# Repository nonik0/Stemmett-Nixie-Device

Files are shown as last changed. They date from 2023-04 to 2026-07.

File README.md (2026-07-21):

# Stemmett Nixie Device

## Description
A Nixie device that uses front-viewed [PL31 socket](https://tubes-store.com/product_info.php?products_id=101) Nixie tubes ([IN-4](https://www.tube-tester.com/sites/nixie/data/in-4/in-4-sh2.htm), [IN-7](https://www.tube-tester.com/sites/nixie/data/IN-7/in-7.htm), [IN-7A](https://www.swissnixie.com/tubes/IN7A/), IN-7B) in different orientations to create makeshift letters and spell things like names! The main board itself has 6 sockets for custom PL31 breakout boards, which have the nixie tube sockets in different orientations to rotate the Nixie tubes. By rotating the tubes we can pseudo-spell things, see images below for example (i.e. "7" rotated 180° to be an "L", or "m" rotated -90° to be a small-sized "E").

The hardware is designed in KiCad and all design files are included in the hardware directory. The hardware consists of the design of the main board PCB and three different versions of the PL31 socket breakout boards. The overall component choices target using simple through-hole components so the PCB is easier to debug, as it is my first PCB design. All cathodes of the nixie tubes are controlled with a single pin with serial, using three 74HC595 shift registers to control the input of the six old school К155ИД1 (K155ID1, SN74141) driver chips for each nixie tube. Each tube anode has a simple MOSFET circuit to be able to PWM each tube individually, allowing each tube to be individually dimmed or turned off. I am using the tiny awesome [NCH8200HV](https://www.tindie.com/products/omnixie/nch8200hv-nixie-high-voltage-power-module/) for the high voltage supply.

The firmware is a PlatformIO-based project targetting the [TinyS3](https://esp32s3.com/tinys3.html) ESP32 dev board. All source files are included in the firmware directory. The firmware will cycle through various different animations, returning to the configured name/word between each. It has a basic HTTP UX with REST interface to update settings--enable/disable animations, changing brightness, etc. It is simple to customize the firmware to any tube configuration by creating a new one in [tubeConfiguration.h](firmware/tubeConfiguration.h).

## Bowen Nixie Device
See the [Bowen Nixie Device README](hardware/kicad/bowen-nixie-device/README.md).

## Images

#### PCB Layout and Bare PCBs
circuitboard
photoof2devices

#### Wood Block to Enclosure
<p align="center" width="100%">
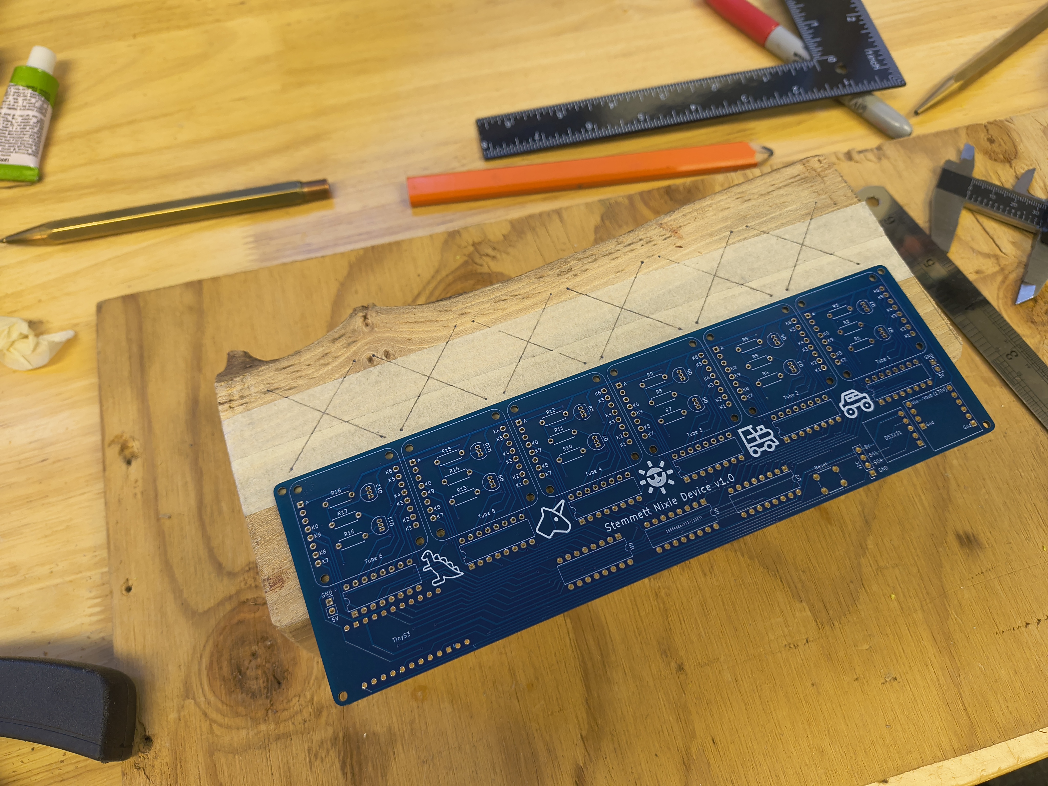
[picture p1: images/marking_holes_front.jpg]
  
</p>
<p align="center" width="100%">
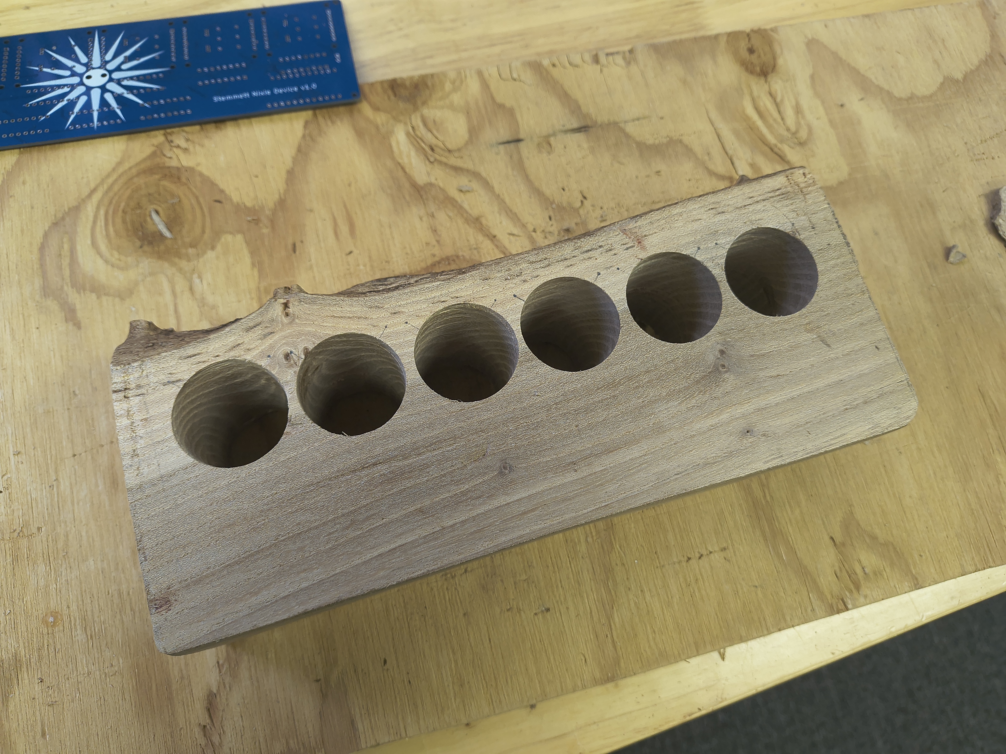
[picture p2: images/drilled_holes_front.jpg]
  
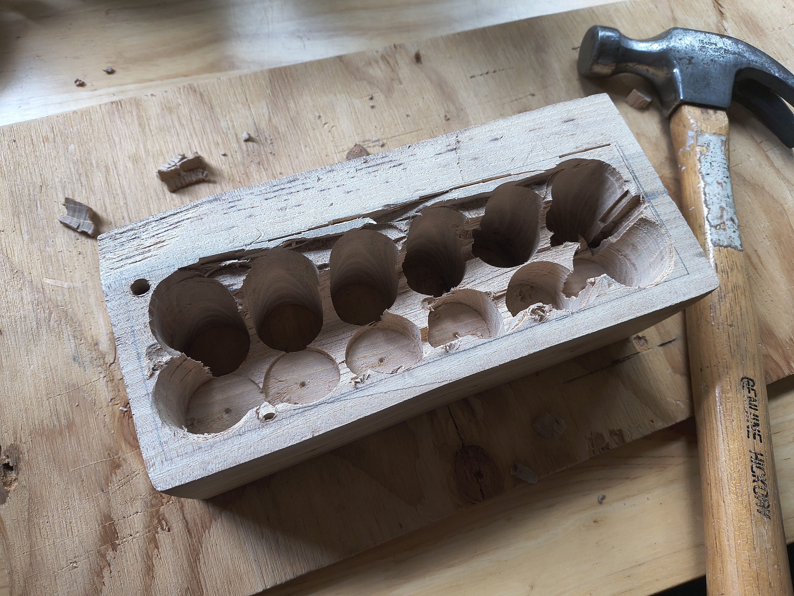
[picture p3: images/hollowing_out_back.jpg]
  
</p>
<p align="center" width="100%">
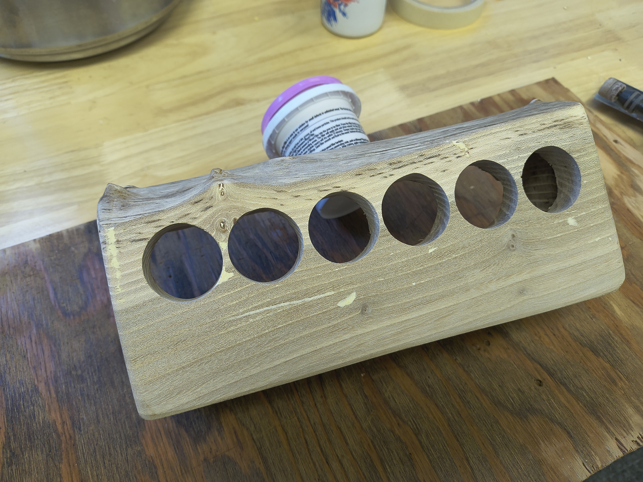
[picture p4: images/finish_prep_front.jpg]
  
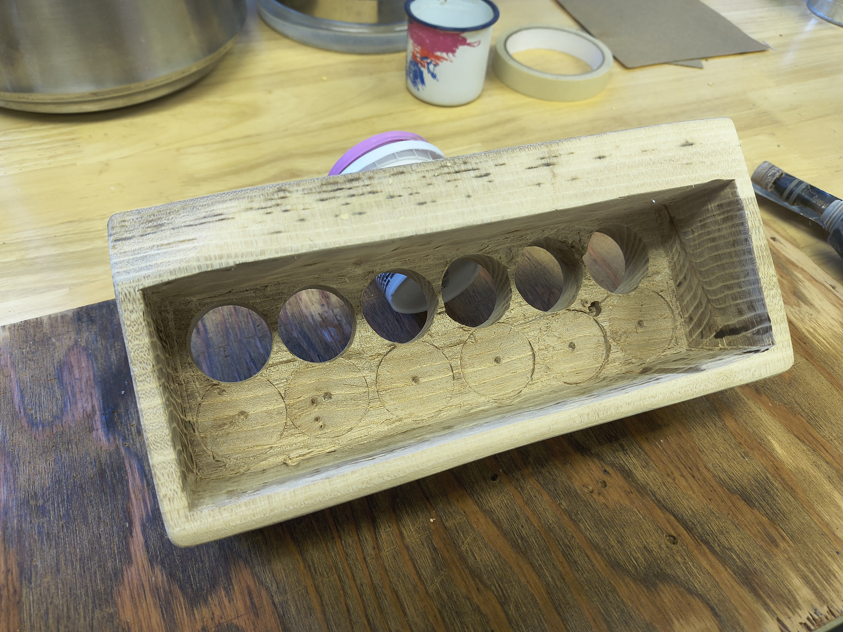
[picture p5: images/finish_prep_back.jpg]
  
</p>

#### Fitting and Finishing

<p align="center" width="100%">
  
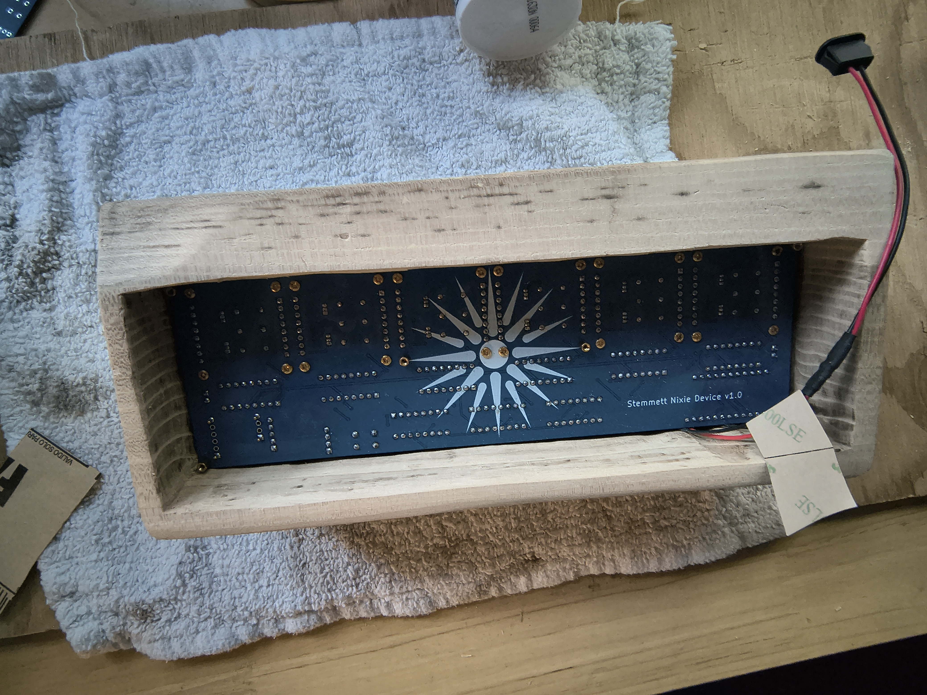
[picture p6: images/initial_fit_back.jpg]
  
</p>
<p align="center" width="100%">
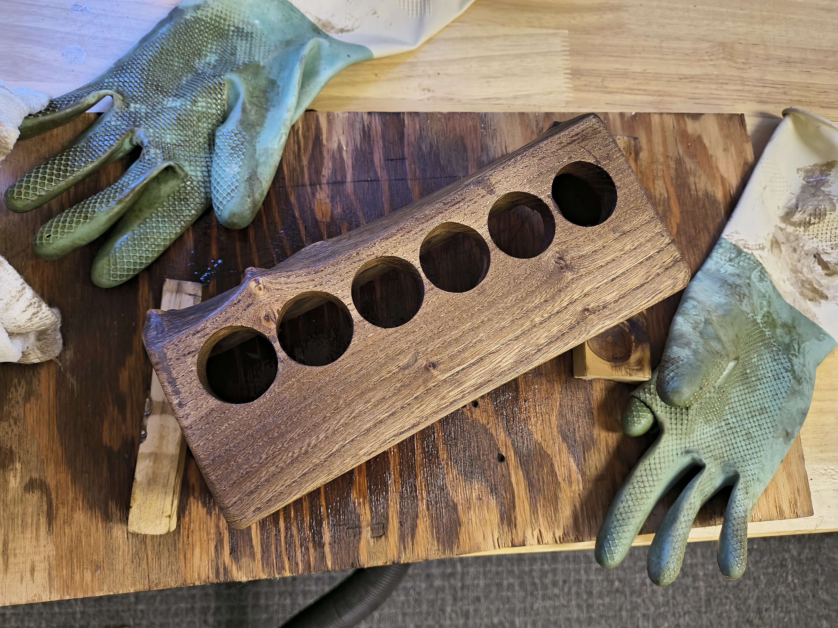
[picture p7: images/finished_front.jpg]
  
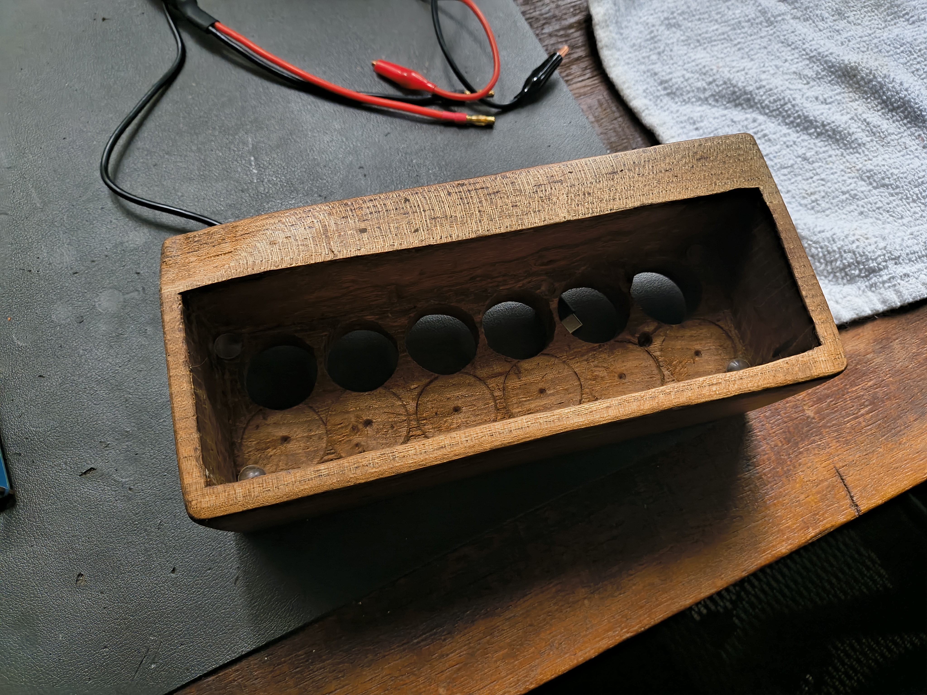
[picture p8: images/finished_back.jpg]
  
</p>

#### Finished Enclosure

<p align="center" width="100%">
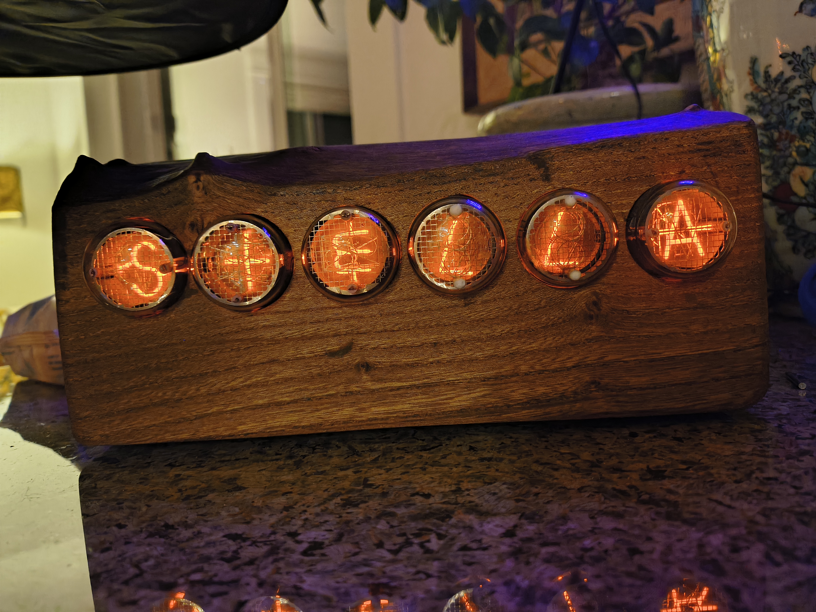
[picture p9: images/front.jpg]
  
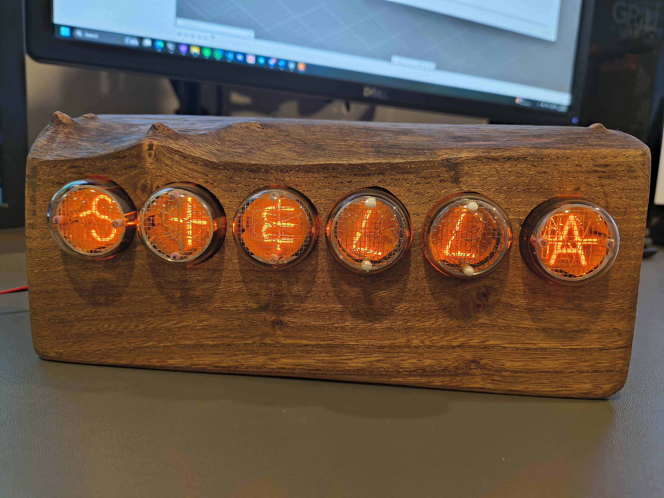
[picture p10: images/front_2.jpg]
  
</p>

#### Alternate Enclosure
<p align="center" width="100%">
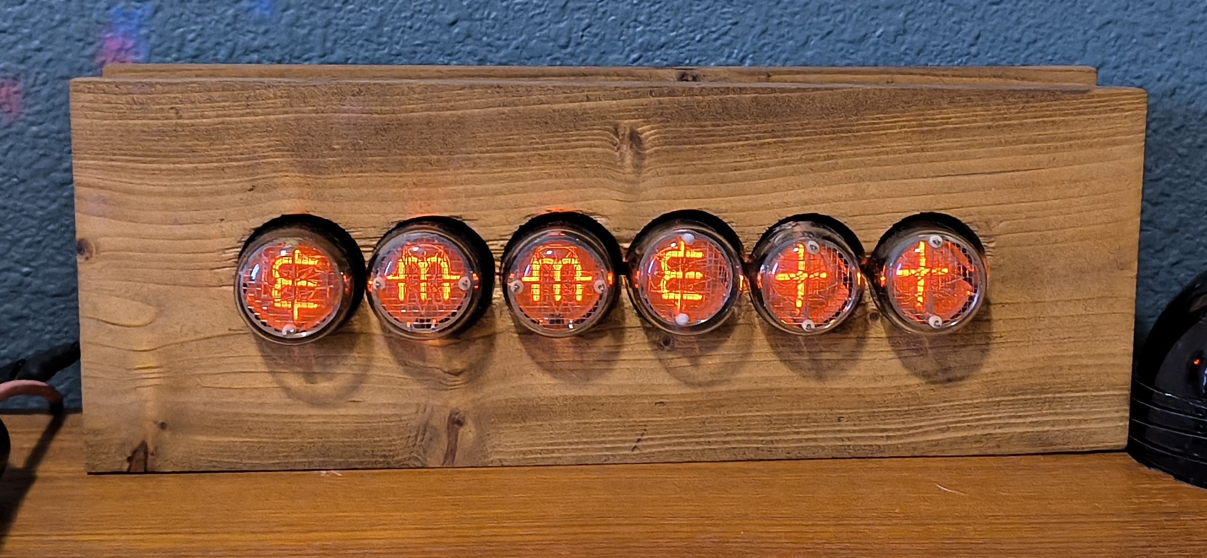
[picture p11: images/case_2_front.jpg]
  
</p>

## Animations

<a href="images/glitch_anim.mp4">Glitch Animation</a>
<a href="images/random_scan_anim.mp4">Random Scan Animation</a>







TODO: animations in better lighting...

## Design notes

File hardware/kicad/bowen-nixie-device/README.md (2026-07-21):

# Bowen Nixie Device

## Description
A Nixie device that is a successor/companion to the original Stemmett Nixie Device. Like its predecessor, it uses front-viewed [PL31 socket](https://tubes-store.com/product_info.php?products_id=101) Nixie tubes ([IN-4](https://www.tube-tester.com/sites/nixie/data/in-4/in-4-sh2.htm), [IN-7](https://www.tube-tester.com/sites/nixie/data/IN-7/in-7.htm), [IN-7A](https://www.swissnixie.com/tubes/IN7A/), IN-7B) to spell words with makeshift letters. These Nixie tubes plug into custom PL31 breakout boards which orient the tubes in different rotations. Then these tube breakout boards plug into the main board that supports control of 4 tubes in total. More breakout board variations were added from the original project to enable more letter possible.

Bowen Nixie Device differs from the prior project primarily through some different component choices. In this version, I am primarily using SMD components and have included discrete cathode control for each tube, i.e. every cathode gets its own transistor for control. Cathode control remains the same as before, using a series of shift registers to control the gate for each transistor that controls the cathode on each tube. Each tube still has an anode control circuit for switching the high voltage on the tube's anode, allowing manual control of each tube's brightness with PWM. 

Hardware prototype is pending, firmware

## Work Left
- get new main board and tube breakout boards made
- create initial prototype, vet hardware design
- update existing firmware to work with new board and tube configuration

## Images

#### PCB Layout
schematic
<img width="1062" alt="layout" src="https://github.com/user-attachments/assets/d3f8a463-915f-4086-bd1c-70b7b26c18d1"">

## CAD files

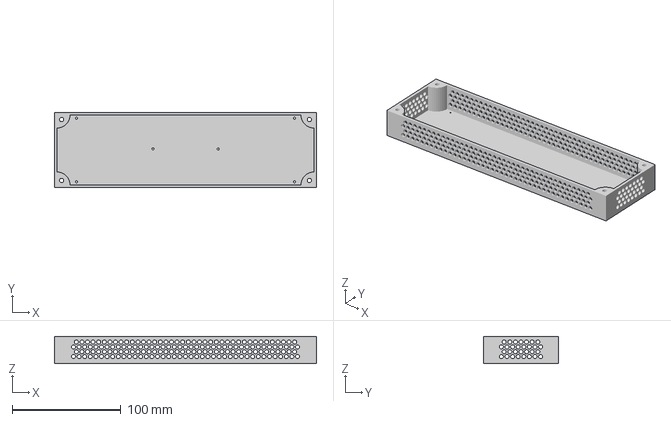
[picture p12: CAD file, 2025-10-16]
hardware/Stemmett Shroud.3mf
240.5 x 68.9 x 25.0 mm

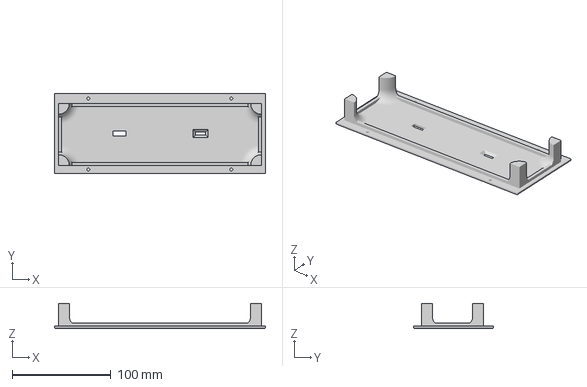
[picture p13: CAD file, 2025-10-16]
hardware/Stemmett Case Backplate.3mf
214.0 x 81.0 x 25.5 mm

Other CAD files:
hardware/Stemmett Case Backplate.f3d
hardware/Stemmett Shroud.f3d

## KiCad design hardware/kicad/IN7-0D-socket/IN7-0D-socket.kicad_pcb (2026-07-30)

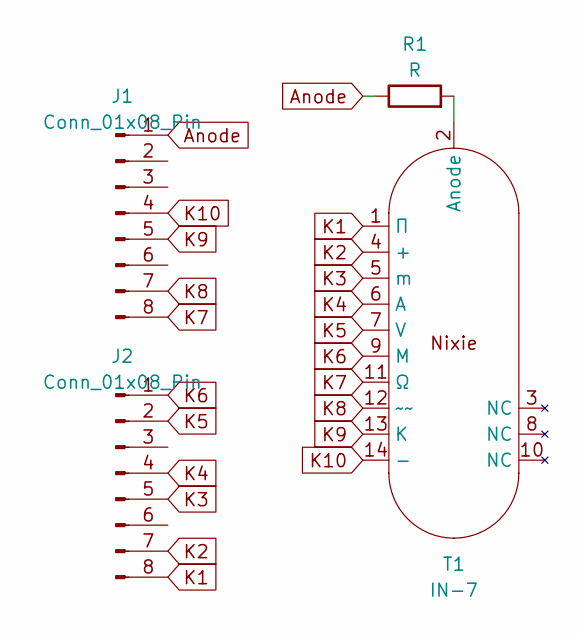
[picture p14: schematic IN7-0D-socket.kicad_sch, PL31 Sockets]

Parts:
J1, J2: Conn_01x08_Pin; PinHeader_1x08_P2.54mm_Vertical
R1: R; R_Axial_DIN0207_L6.3mm_D2.5mm_P7.62mm_Horizontal
T1: IN-7; PL31 (IN4 family)

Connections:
Anode: J1.1, R1.1
K1: J2.8, T1.1 (П)
K2: J2.7, T1.4 (+)
K3: J2.5, T1.5 (m)
K4: J2.4, T1.6 (A)
K5: J2.2, T1.7 (V)
K6: J2.1, T1.9 (M)
K7: J1.8, T1.11 (Ω)
K8: J1.7, T1.12 (~~)
K9: J1.5, T1.13 (К)
K10: J1.4, T1.14 (-)
unnamed: R1.2, T1.2 (Anode)

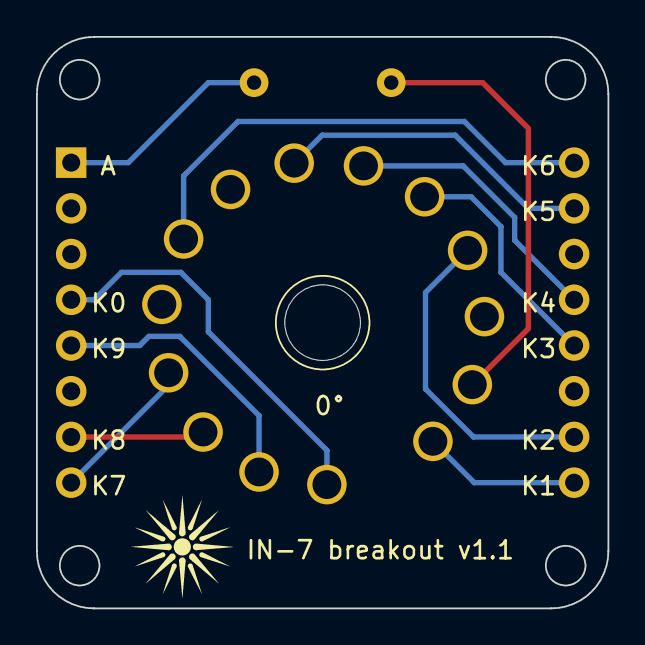
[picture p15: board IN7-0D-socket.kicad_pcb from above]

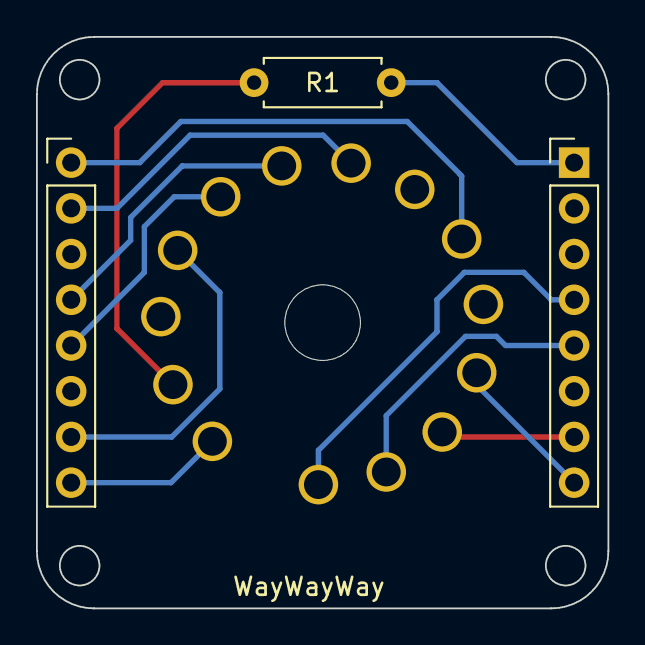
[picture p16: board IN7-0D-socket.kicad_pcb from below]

Board: 2 copper layers, 31.8 x 31.8 mm, 4 parts (3 on the bottom side), 12 nets.

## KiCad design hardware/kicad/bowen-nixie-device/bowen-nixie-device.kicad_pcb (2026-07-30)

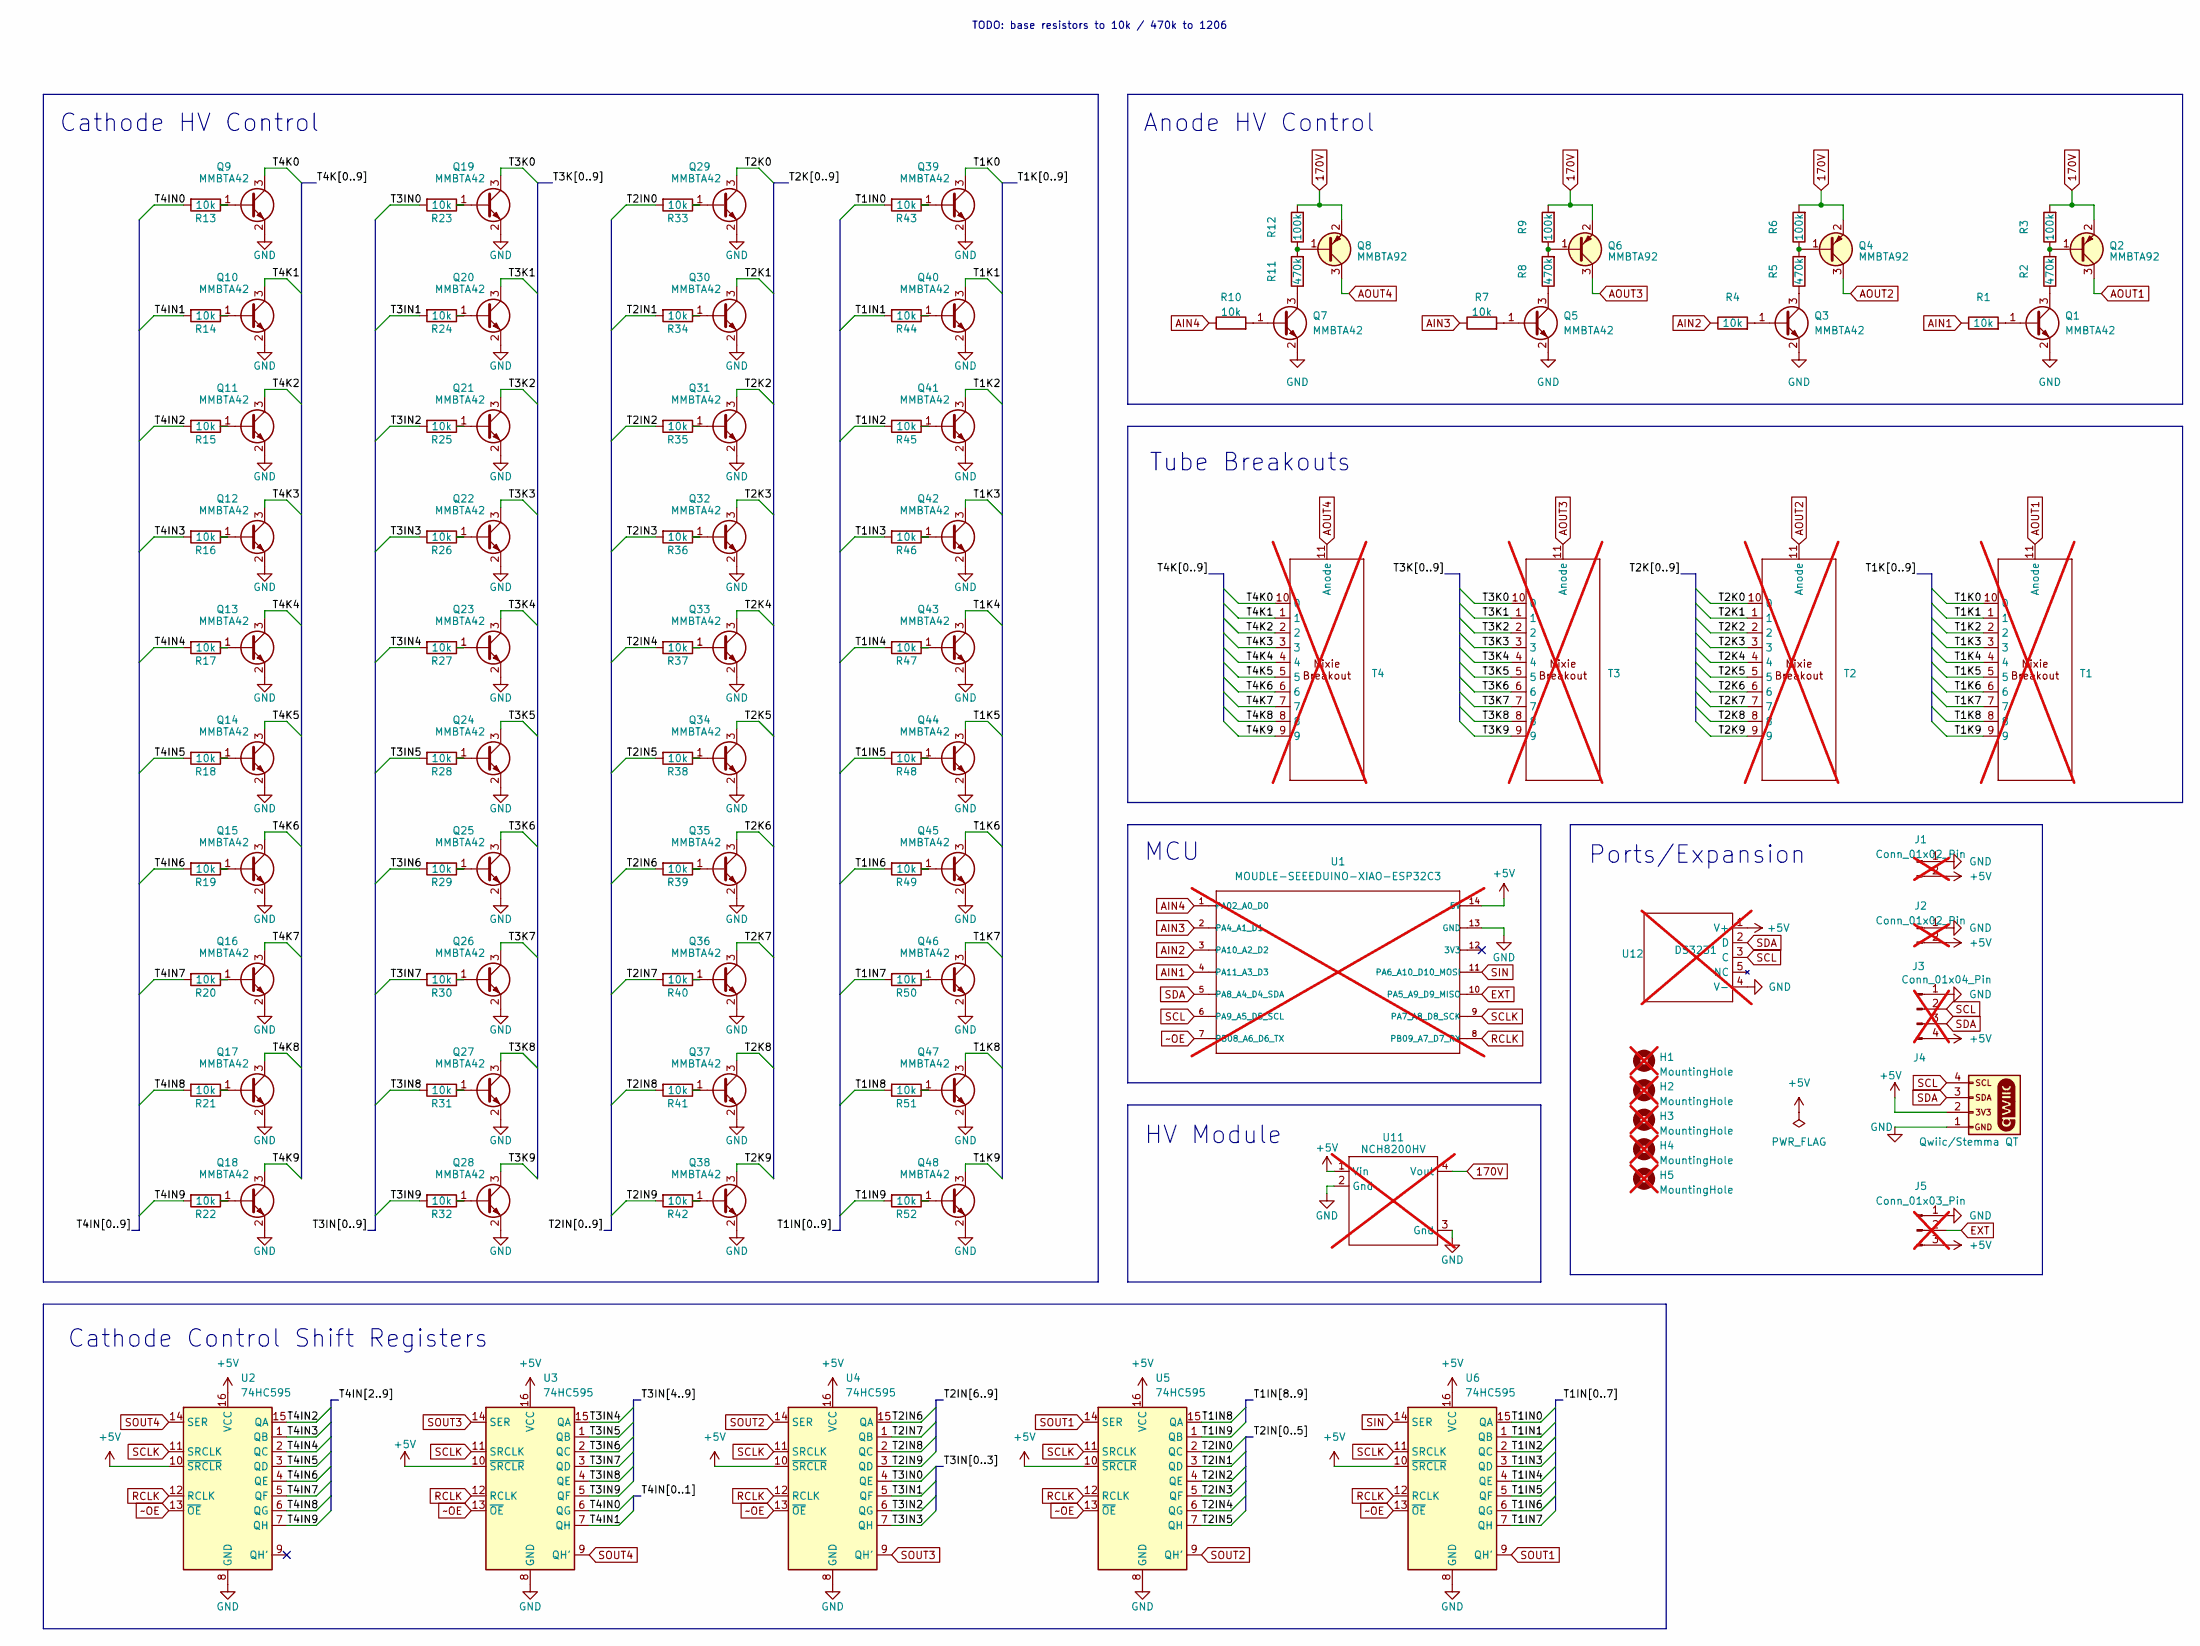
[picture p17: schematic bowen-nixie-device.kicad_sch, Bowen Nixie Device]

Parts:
H1, H2, H3, H4, H5: MountingHole; MountingHole_2.2mm_M2_DIN965_Pad; not fitted
J1, J2: Conn_01x02_Pin; PinSocket_1x02_P2.54mm_Vertical; not fitted
J3: Conn_01x04_Pin; PinSocket_1x04_P2.54mm_Vertical; not fitted
J4: Qwiic/Stemma QT; JST_1x04_P1.0mm_Vertical_SMD
J5: Conn_01x03_Pin; PinSocket_1x03_P2.54mm_Vertical; not fitted
Q1, Q3, Q5, Q7, Q9, Q10, Q11, Q12, Q13, Q14, Q15, Q16, Q17, Q18, Q19, Q20, Q21, Q22, Q23, Q24, Q25, Q26, Q27, Q28, Q29, Q30, Q31, Q32, Q33, Q34, Q35, Q36, Q37, Q38, Q39, Q40, Q41, Q42, Q43, Q44, Q45, Q46, Q47, Q48: MMBTA42; SOT-23
Q2, Q4, Q6, Q8: MMBTA92; SOT-23
R1, R4, R7, R10, R13, R14, R15, R16, R17, R18, R19, R20, R21, R22, R23, R24, R25, R26, R27, R28, R29, R30, R31, R32, R33, R34, R35, R36, R37, R38, R39, R40, R41, R42, R43, R44, R45, R46, R47, R48, R49, R50, R51, R52: 10k; R_0603_1608Metric
R2, R5, R8, R11: 470k; R_1206_3216Metric
R3, R6, R9, R12: 100k; R_0603_1608Metric
T1, T2, T3, T4: PL31 Socket Breakout; not fitted
U1: MOUDLE-SEEEDUINO-XIAO-ESP32C3; XIAO-ESP32-C3-DIP; not fitted
U2, U3, U4, U5, U6: 74HC595; SOIC-16_4.55x10.3mm_P1.27mm
U11: NCH8200HV; not fitted
U12: DS3231; DS3231 Breakout; not fitted

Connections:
170V: Q2.2 (E), Q4.2 (E), Q6.2 (E), Q8.2 (E), R3.2, R6.2, R9.2, R12.2, U11.4 (Vout)
+5V: J1.2, J2.2, J3.4, J4.2, J5.3, U1.14 (5V), U2.10 (~SRCLR), U2.16 (VCC), U3.10 (~SRCLR), U3.16 (VCC), U4.10 (~SRCLR), U4.16 (VCC), U5.10 (~SRCLR), U5.16 (VCC), U6.10 (~SRCLR), U6.16 (VCC), U11.1 (Vin), U12.1 (V+)
/T1IN0: R43.2, U6.15 (QA)
/T1IN1: R44.2, U6.1 (QB)
/T1IN2: R45.2, U6.2 (QC)
/T1IN3: R46.2, U6.3 (QD)
/T1IN4: R47.2, U6.4 (QE)
/T1IN5: R48.2, U6.5 (QF)
/T1IN6: R49.2, U6.6 (QG)
/T1IN7: R50.2, U6.7 (QH)
/T1IN8: R51.2, U5.15 (QA)
/T1IN9: R52.2, U5.1 (QB)
/T1K0: Q39.3 (C), T1.10 (0)
/T1K1: Q40.3 (C), T1.1
/T1K2: Q41.3 (C), T1.2
/T1K3: Q42.3 (C), T1.3
/T1K4: Q43.3 (C), T1.4
/T1K5: Q44.3 (C), T1.5
/T1K6: Q45.3 (C), T1.6
/T1K7: Q46.3 (C), T1.7
/T1K8: Q47.3 (C), T1.8
/T1K9: Q48.3 (C), T1.9
/T2IN0: R33.2, U5.2 (QC)
/T2IN1: R34.2, U5.3 (QD)
/T2IN2: R35.2, U5.4 (QE)
/T2IN3: R36.2, U5.5 (QF)
/T2IN4: R37.2, U5.6 (QG)
/T2IN5: R38.2, U5.7 (QH)
/T2IN6: R39.2, U4.15 (QA)
/T2IN7: R40.2, U4.1 (QB)
/T2IN8: R41.2, U4.2 (QC)
/T2IN9: R42.2, U4.3 (QD)
/T2K0: Q29.3 (C), T2.10 (0)
/T2K1: Q30.3 (C), T2.1
/T2K2: Q31.3 (C), T2.2
/T2K3: Q32.3 (C), T2.3
/T2K4: Q33.3 (C), T2.4
/T2K5: Q34.3 (C), T2.5
/T2K6: Q35.3 (C), T2.6
/T2K7: Q36.3 (C), T2.7
/T2K8: Q37.3 (C), T2.8
/T2K9: Q38.3 (C), T2.9
/T3IN0: R23.2, U4.4 (QE)
/T3IN1: R24.2, U4.5 (QF)
/T3IN2: R25.2, U4.6 (QG)
/T3IN3: R26.2, U4.7 (QH)
/T3IN4: R27.2, U3.15 (QA)
/T3IN5: R28.2, U3.1 (QB)
/T3IN6: R29.2, U3.2 (QC)
/T3IN7: R30.2, U3.3 (QD)
/T3IN8: R31.2, U3.4 (QE)
/T3IN9: R32.2, U3.5 (QF)
/T3K0: Q19.3 (C), T3.10 (0)
/T3K1: Q20.3 (C), T3.1
/T3K2: Q21.3 (C), T3.2
/T3K3: Q22.3 (C), T3.3
/T3K4: Q23.3 (C), T3.4
/T3K5: Q24.3 (C), T3.5
/T3K6: Q25.3 (C), T3.6
/T3K7: Q26.3 (C), T3.7
/T3K8: Q27.3 (C), T3.8
/T3K9: Q28.3 (C), T3.9
/T4IN0: R13.2, U3.6 (QG)
/T4IN1: R14.2, U3.7 (QH)
/T4IN2: R15.2, U2.15 (QA)
/T4IN3: R16.2, U2.1 (QB)
/T4IN4: R17.2, U2.2 (QC)
/T4IN5: R18.2, U2.3 (QD)
/T4IN6: R19.2, U2.4 (QE)
/T4IN7: R20.2, U2.5 (QF)
/T4IN8: R21.2, U2.6 (QG)
/T4IN9: R22.2, U2.7 (QH)
/T4K0: Q9.3 (C), T4.10 (0)
/T4K1: Q10.3 (C), T4.1
/T4K2: Q11.3 (C), T4.2
/T4K3: Q12.3 (C), T4.3
/T4K4: Q13.3 (C), T4.4
/T4K5: Q14.3 (C), T4.5
/T4K6: Q15.3 (C), T4.6
/T4K7: Q16.3 (C), T4.7
/T4K8: Q17.3 (C), T4.8
/T4K9: Q18.3 (C), T4.9
AIN1: R1.1, U1.4 (PA11_A3_D3)
AIN2: R4.1, U1.3 (PA10_A2_D2)
AIN3: R7.1, U1.2 (PA4_A1_D1)
AIN4: R10.1, U1.1 (PA02_A0_D0)
AOUT1: Q2.3 (C), T1.11 (Anode)
AOUT2: Q4.3 (C), T2.11 (Anode)
AOUT3: Q6.3 (C), T3.11 (Anode)
AOUT4: Q8.3 (C), T4.11 (Anode)
EXT: J5.2, U1.10 (PA5_A9_D9_MISO)
GND: J1.1, J2.1, J3.1, J4.1, J5.1, Q1.2 (E), Q3.2 (E), Q5.2 (E), Q7.2 (E), Q9.2 (E), Q10.2 (E), Q11.2 (E), Q12.2 (E), Q13.2 (E), Q14.2 (E), Q15.2 (E), Q16.2 (E), Q17.2 (E), Q18.2 (E), Q19.2 (E), Q20.2 (E), Q21.2 (E), Q22.2 (E), Q23.2 (E), Q24.2 (E), Q25.2 (E), Q26.2 (E), Q27.2 (E), Q28.2 (E), Q29.2 (E), Q30.2 (E), Q31.2 (E), Q32.2 (E), Q33.2 (E), Q34.2 (E), Q35.2 (E), Q36.2 (E), Q37.2 (E), Q38.2 (E), Q39.2 (E), Q40.2 (E), Q41.2 (E), Q42.2 (E), Q43.2 (E), Q44.2 (E), Q45.2 (E), Q46.2 (E), Q47.2 (E), Q48.2 (E), U1.13 (GND), U2.8 (GND), U3.8 (GND), U4.8 (GND), U5.8 (GND), U6.8 (GND), U11.2 (Gnd), U11.3 (Gnd), U12.4 (V-)
unnamed: Q1.1 (B), R1.2
unnamed: Q1.3 (C), R2.1
unnamed: Q2.1 (B), R2.2, R3.1
unnamed: Q3.1 (B), R4.2
unnamed: Q3.3 (C), R5.1
unnamed: Q4.1 (B), R5.2, R6.1
unnamed: Q5.1 (B), R7.2
unnamed: Q5.3 (C), R8.1
unnamed: Q6.1 (B), R8.2, R9.1
unnamed: Q7.1 (B), R10.2
unnamed: Q7.3 (C), R11.1
unnamed: Q8.1 (B), R11.2, R12.1
unnamed: Q9.1 (B), R13.1
unnamed: Q10.1 (B), R14.1
unnamed: Q11.1 (B), R15.1
unnamed: Q12.1 (B), R16.1
unnamed: Q13.1 (B), R17.1
unnamed: Q14.1 (B), R18.1
unnamed: Q15.1 (B), R19.1
unnamed: Q16.1 (B), R20.1
unnamed: Q17.1 (B), R21.1
unnamed: Q18.1 (B), R22.1
unnamed: Q19.1 (B), R23.1
unnamed: Q20.1 (B), R24.1
unnamed: Q21.1 (B), R25.1
unnamed: Q22.1 (B), R26.1
unnamed: Q23.1 (B), R27.1
unnamed: Q24.1 (B), R28.1
unnamed: Q25.1 (B), R29.1
unnamed: Q26.1 (B), R30.1
unnamed: Q27.1 (B), R31.1
unnamed: Q28.1 (B), R32.1
unnamed: Q29.1 (B), R33.1
unnamed: Q30.1 (B), R34.1
unnamed: Q31.1 (B), R35.1
unnamed: Q32.1 (B), R36.1
unnamed: Q33.1 (B), R37.1
unnamed: Q34.1 (B), R38.1
unnamed: Q35.1 (B), R39.1
unnamed: Q36.1 (B), R40.1
unnamed: Q37.1 (B), R41.1
unnamed: Q38.1 (B), R42.1
unnamed: Q39.1 (B), R43.1
unnamed: Q40.1 (B), R44.1
unnamed: Q41.1 (B), R45.1
unnamed: Q42.1 (B), R46.1
unnamed: Q43.1 (B), R47.1
unnamed: Q44.1 (B), R48.1
unnamed: Q45.1 (B), R49.1
unnamed: Q46.1 (B), R50.1
unnamed: Q47.1 (B), R51.1
unnamed: Q48.1 (B), R52.1
RCLK: U1.8 (PB09_A7_D7_RX), U2.12 (RCLK), U3.12 (RCLK), U4.12 (RCLK), U5.12 (RCLK), U6.12 (RCLK)
SCL: J3.2, J4.4, U1.6 (PA9_A5_D5_SCL), U12.3 (C)
SCLK: U1.9 (PA7_A8_D8_SCK), U2.11 (SRCLK), U3.11 (SRCLK), U4.11 (SRCLK), U5.11 (SRCLK), U6.11 (SRCLK)
SDA: J3.3, J4.3, U1.5 (PA8_A4_D4_SDA), U12.2 (D)
SIN: U1.11 (PA6_A10_D10_MOSI), U6.14 (SER)
SOUT1: U5.14 (SER), U6.9 (QH')
SOUT2: U4.14 (SER), U5.9 (QH')
SOUT3: U3.14 (SER), U4.9 (QH')
SOUT4: U2.14 (SER), U3.9 (QH')
~OE: U1.7 (PB08_A6_D6_TX), U2.13 (~OE), U3.13 (~OE), U4.13 (~OE), U5.13 (~OE), U6.13 (~OE)

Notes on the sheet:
TODO: base resistors to 10k / 470k to 1206
Cathode Control Shift Registers
Cathode HV Control
HV Module
Anode HV Control
Tube Breakouts
Ports/Expansion
MCU

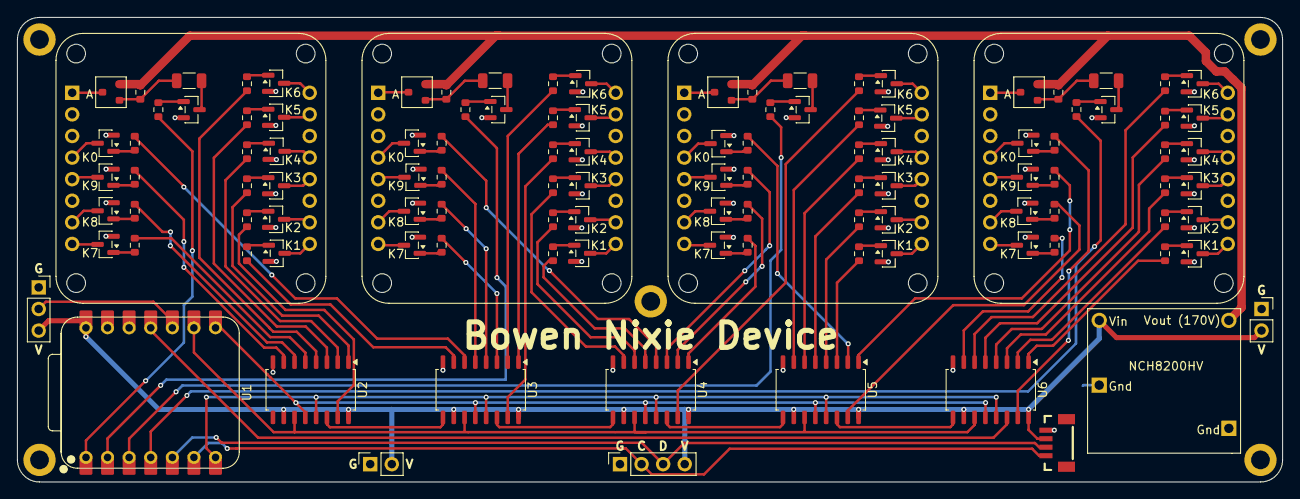
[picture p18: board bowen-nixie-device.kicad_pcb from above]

Board: 2 copper layers, 148.8 x 54.6 mm, 121 parts (0 on the bottom side), 154 nets.

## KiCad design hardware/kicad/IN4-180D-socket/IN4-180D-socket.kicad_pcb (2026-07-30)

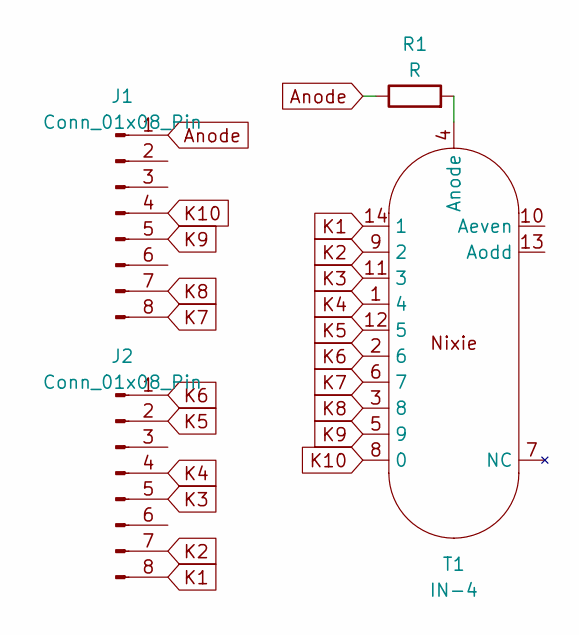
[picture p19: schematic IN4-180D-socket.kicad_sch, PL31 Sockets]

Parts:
J1, J2: Conn_01x08_Pin; PinHeader_1x08_P2.54mm_Vertical
R1: R; R_Axial_DIN0207_L6.3mm_D2.5mm_P7.62mm_Horizontal
T1: IN-4; PL31 (IN4 rotation)

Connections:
Anode: J1.1, R1.1
K1: J2.8, T1.14 (1)
K2: J2.7, T1.9 (2)
K3: J2.5, T1.11 (3)
K4: J2.4, T1.1 (4)
K5: J2.2, T1.12 (5)
K6: J2.1, T1.2 (6)
K7: J1.8, T1.6 (7)
K8: J1.7, T1.3 (8)
K9: J1.5, T1.5 (9)
K10: J1.4, T1.8 (0)
unnamed: R1.2, T1.4 (Anode)

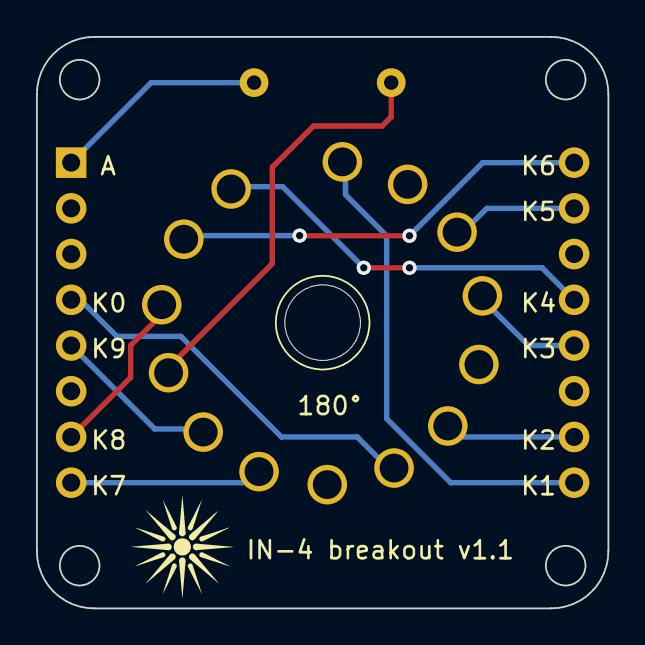
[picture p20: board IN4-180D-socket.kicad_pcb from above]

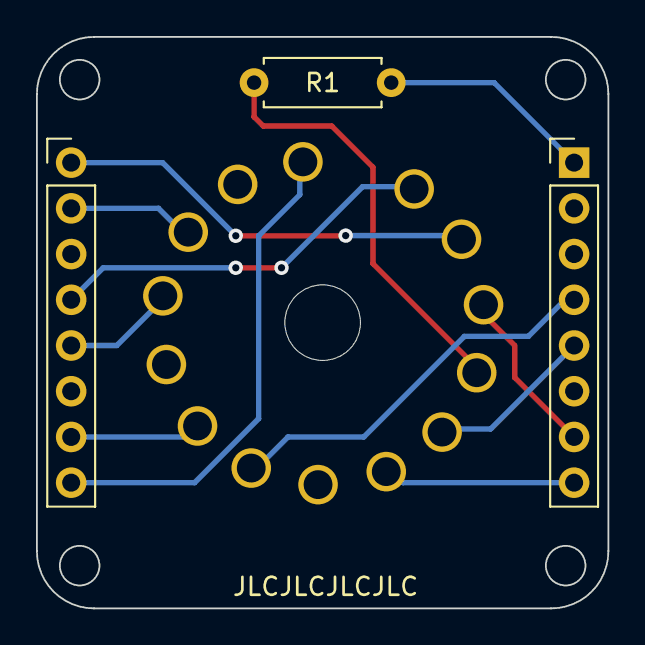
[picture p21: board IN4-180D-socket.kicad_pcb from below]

Board: 2 copper layers, 31.8 x 31.8 mm, 4 parts (3 on the bottom side), 12 nets.

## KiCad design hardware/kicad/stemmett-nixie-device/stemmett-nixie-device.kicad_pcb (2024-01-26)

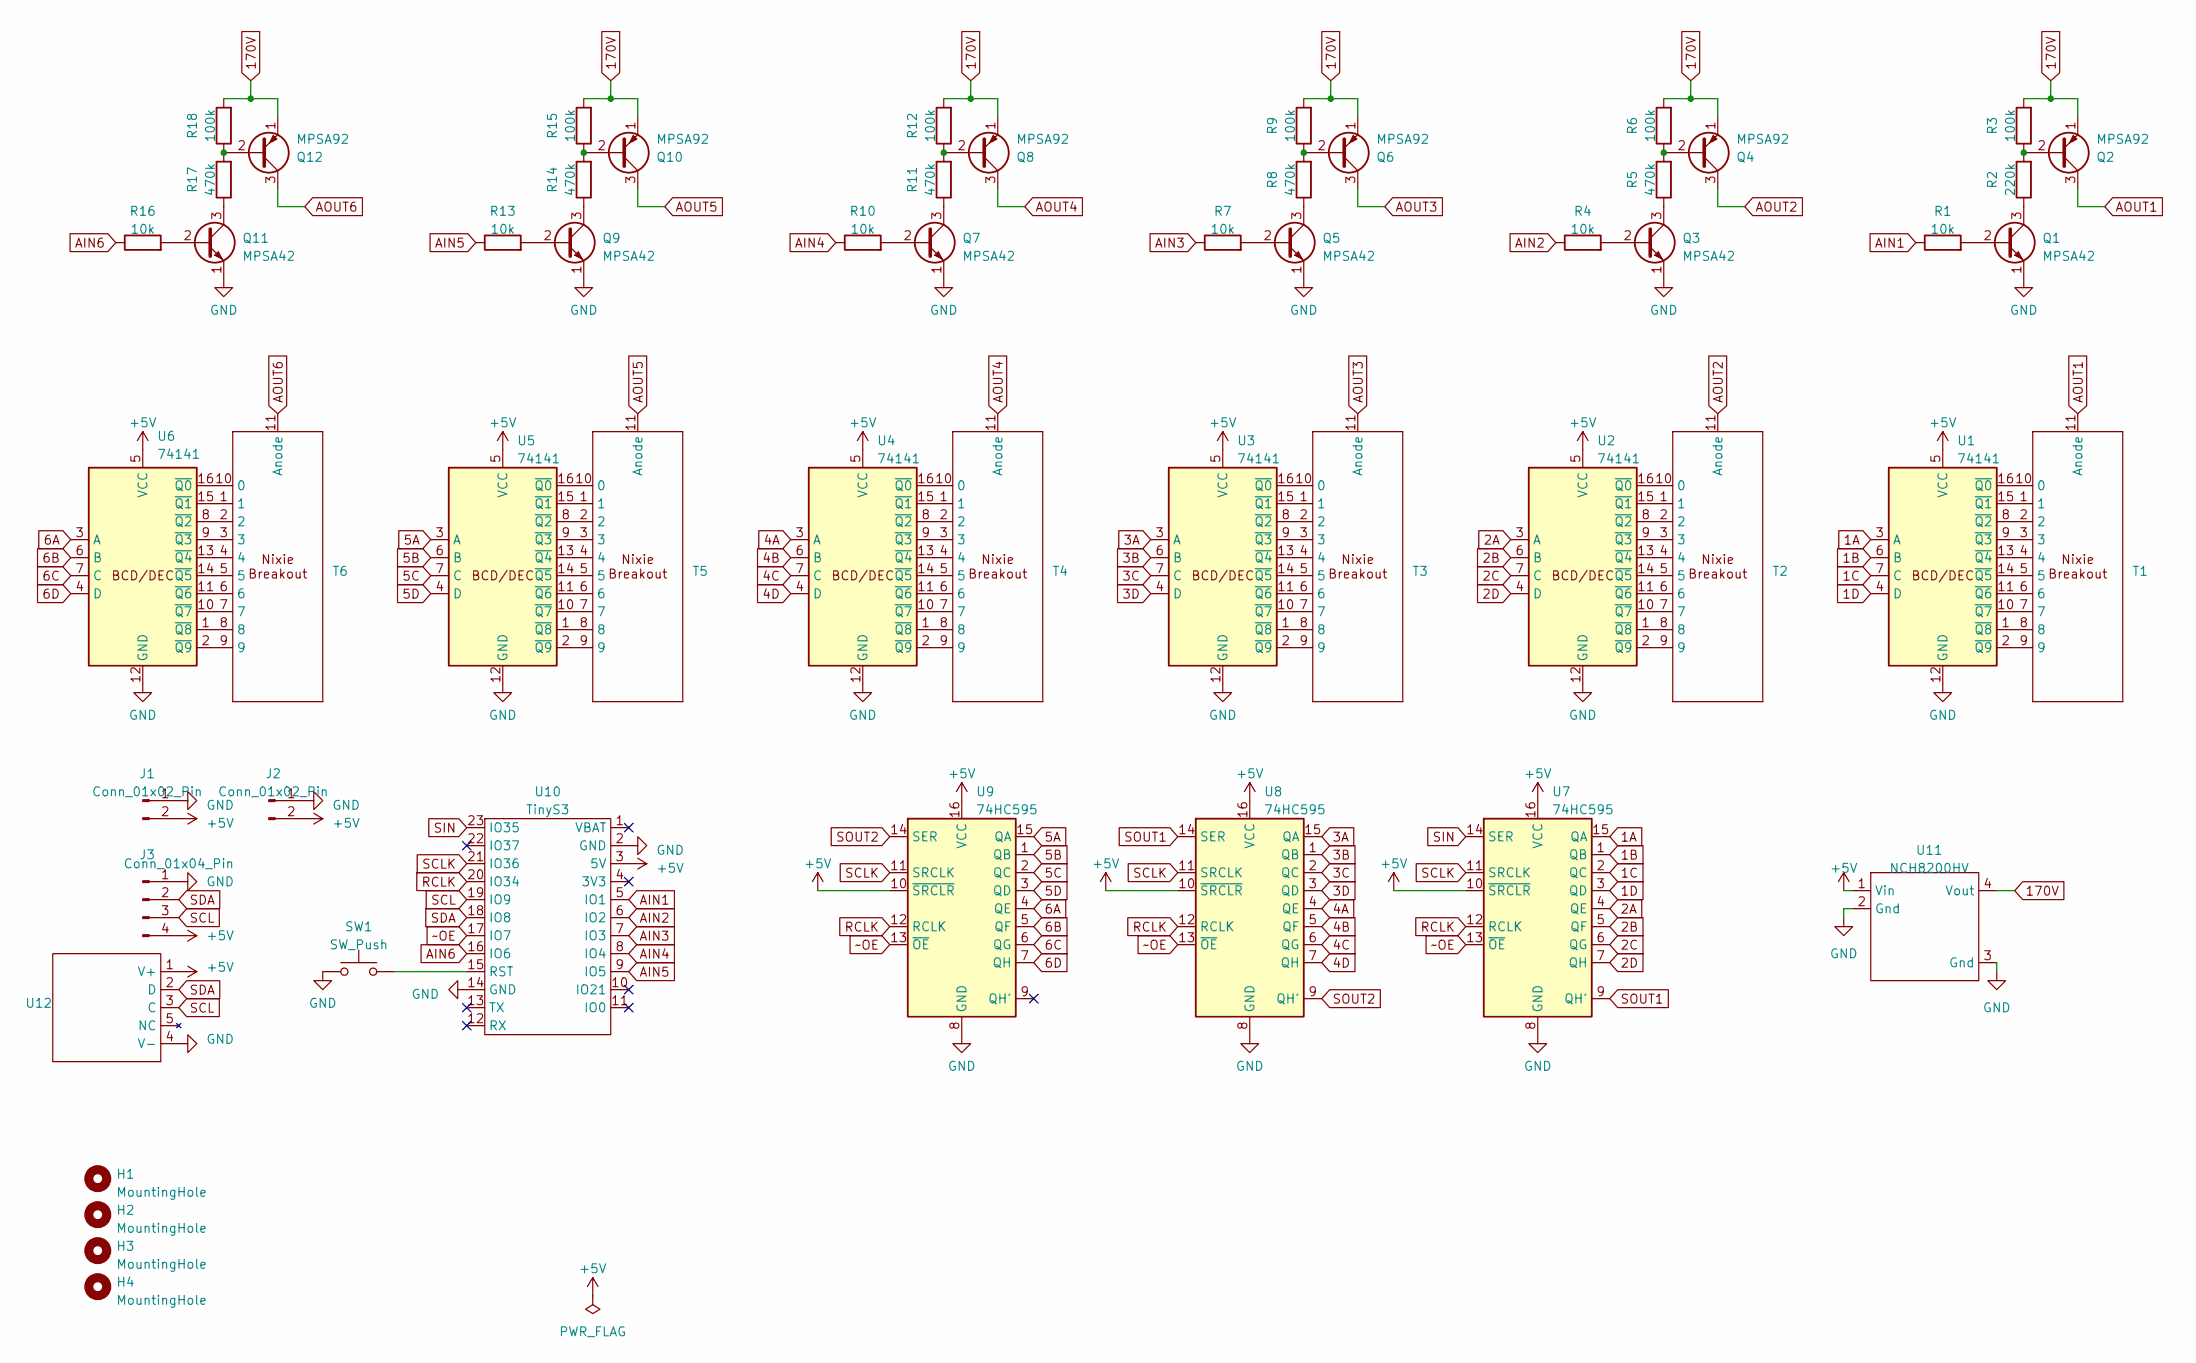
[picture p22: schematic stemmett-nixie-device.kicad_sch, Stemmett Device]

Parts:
H1, H2, H3, H4: MountingHole; MountingHole_2.2mm_M2
J1, J2: Conn_01x02_Pin; PinSocket_1x02_P2.54mm_Vertical
J3: Conn_01x04_Pin; PinSocket_1x04_P2.54mm_Vertical
Q1, Q3, Q5, Q7, Q9, Q11: MPSA42; TO-92_Inline
Q2, Q4, Q6, Q8, Q10, Q12: MPSA92; TO-92_Inline
R1, R4, R7, R10, R13, R16: 10k; R_Axial_DIN0207_L6.3mm_D2.5mm_P7.62mm_Horizontal
R2: 220k; R_Axial_DIN0207_L6.3mm_D2.5mm_P7.62mm_Horizontal
R3, R6, R9, R12, R15, R18: 100k; R_Axial_DIN0207_L6.3mm_D2.5mm_P7.62mm_Horizontal
R5, R8, R11, R14, R17: 470k; R_Axial_DIN0207_L6.3mm_D2.5mm_P7.62mm_Horizontal
SW1: SW_Push; SW_PUSH_6mm
T1, T2, T3, T4, T5, T6: PL31 Socket Breakout
U1, U2, U3, U4, U5, U6: 74141; DIP-16_W7.62mm
U7, U8, U9: 74HC595; DIP-16_W7.62mm
U10: TinyS3
U11: NCH8200HV
U12: DS3231 Breakout

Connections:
1A: U1.3 (A), U7.15 (QA)
1B: U1.6 (B), U7.1 (QB)
1C: U1.7 (C), U7.2 (QC)
1D: U1.4 (D), U7.3 (QD)
2A: U2.3 (A), U7.4 (QE)
2B: U2.6 (B), U7.5 (QF)
2C: U2.7 (C), U7.6 (QG)
2D: U2.4 (D), U7.7 (QH)
3A: U3.3 (A), U8.15 (QA)
3B: U3.6 (B), U8.1 (QB)
3C: U3.7 (C), U8.2 (QC)
3D: U3.4 (D), U8.3 (QD)
4A: U4.3 (A), U8.4 (QE)
4B: U4.6 (B), U8.5 (QF)
4C: U4.7 (C), U8.6 (QG)
4D: U4.4 (D), U8.7 (QH)
5A: U5.3 (A), U9.15 (QA)
5B: U5.6 (B), U9.1 (QB)
5C: U5.7 (C), U9.2 (QC)
5D: U5.4 (D), U9.3 (QD)
6A: U6.3 (A), U9.4 (QE)
6B: U6.6 (B), U9.5 (QF)
6C: U6.7 (C), U9.6 (QG)
6D: U6.4 (D), U9.7 (QH)
170V: Q2.1 (E), Q4.1 (E), Q6.1 (E), Q8.1 (E), Q10.1 (E), Q12.1 (E), R3.2, R6.2, R9.2, R12.2, R15.2, R18.2, U11.4 (Vout)
+5V: J1.2, J2.2, J3.4, U1.5 (VCC), U2.5 (VCC), U3.5 (VCC), U4.5 (VCC), U5.5 (VCC), U6.5 (VCC), U7.10 (~SRCLR), U7.16 (VCC), U8.10 (~SRCLR), U8.16 (VCC), U9.10 (~SRCLR), U9.16 (VCC), U10.3 (5V), U11.1 (Vin), U12.1 (V+)
AIN1: R1.1, U10.5 (IO1)
AIN2: R4.1, U10.6 (IO2)
AIN3: R7.1, U10.7 (IO3)
AIN4: R10.1, U10.8 (IO4)
AIN5: R13.1, U10.9 (IO5)
AIN6: R16.1, U10.16 (IO6)
AOUT1: Q2.3 (C), T1.11 (Anode)
AOUT2: Q4.3 (C), T2.11 (Anode)
AOUT3: Q6.3 (C), T3.11 (Anode)
AOUT4: Q8.3 (C), T4.11 (Anode)
AOUT5: Q10.3 (C), T5.11 (Anode)
AOUT6: Q12.3 (C), T6.11 (Anode)
GND: J1.1, J2.1, J3.1, Q1.1 (E), Q3.1 (E), Q5.1 (E), Q7.1 (E), Q9.1 (E), Q11.1 (E), SW1.1, U1.12 (GND), U2.12 (GND), U3.12 (GND), U4.12 (GND), U5.12 (GND), U6.12 (GND), U7.8 (GND), U8.8 (GND), U9.8 (GND), U10.2 (GND), U10.14 (GND), U11.2 (Gnd), U11.3 (Gnd), U12.4 (V-)
unnamed: Q1.2 (B), R1.2
unnamed: Q1.3 (C), R2.1
unnamed: Q2.2 (B), R2.2, R3.1
unnamed: Q3.2 (B), R4.2
unnamed: Q3.3 (C), R5.1
unnamed: Q4.2 (B), R5.2, R6.1
unnamed: Q5.2 (B), R7.2
unnamed: Q5.3 (C), R8.1
unnamed: Q6.2 (B), R8.2, R9.1
unnamed: Q7.2 (B), R10.2
unnamed: Q7.3 (C), R11.1
unnamed: Q8.2 (B), R11.2, R12.1
unnamed: Q9.2 (B), R13.2
unnamed: Q9.3 (C), R14.1
unnamed: Q10.2 (B), R14.2, R15.1
unnamed: Q11.2 (B), R16.2
unnamed: Q11.3 (C), R17.1
unnamed: Q12.2 (B), R17.2, R18.1
unnamed: T1.10 (0), U1.16 (~Q0)
unnamed: T2.10 (0), U2.16 (~Q0)
unnamed: T3.10 (0), U3.16 (~Q0)
unnamed: T4.10 (0), U4.16 (~Q0)
unnamed: T5.10 (0), U5.16 (~Q0)
unnamed: T6.10 (0), U6.16 (~Q0)
unnamed: T1.1, U1.15 (~Q1)
unnamed: T1.2, U1.8 (~Q2)
unnamed: T1.3, U1.9 (~Q3)
unnamed: T1.4, U1.13 (~Q4)
unnamed: T1.5, U1.14 (~Q5)
unnamed: T1.6, U1.11 (~Q6)
unnamed: T1.7, U1.10 (~Q7)
unnamed: T1.8, U1.1 (~Q8)
unnamed: T1.9, U1.2 (~Q9)
unnamed: T2.1, U2.15 (~Q1)
unnamed: T2.2, U2.8 (~Q2)
unnamed: T2.3, U2.9 (~Q3)
unnamed: T2.4, U2.13 (~Q4)
unnamed: T2.5, U2.14 (~Q5)
unnamed: T2.6, U2.11 (~Q6)
unnamed: T2.7, U2.10 (~Q7)
unnamed: T2.8, U2.1 (~Q8)
unnamed: T2.9, U2.2 (~Q9)
unnamed: T3.1, U3.15 (~Q1)
unnamed: T3.2, U3.8 (~Q2)
unnamed: T3.3, U3.9 (~Q3)
unnamed: T3.4, U3.13 (~Q4)
unnamed: T3.5, U3.14 (~Q5)
unnamed: T3.6, U3.11 (~Q6)
unnamed: T3.7, U3.10 (~Q7)
unnamed: T3.8, U3.1 (~Q8)
unnamed: T3.9, U3.2 (~Q9)
unnamed: T4.1, U4.15 (~Q1)
unnamed: T4.2, U4.8 (~Q2)
unnamed: T4.3, U4.9 (~Q3)
unnamed: T4.4, U4.13 (~Q4)
unnamed: T4.5, U4.14 (~Q5)
unnamed: T4.6, U4.11 (~Q6)
unnamed: T4.7, U4.10 (~Q7)
unnamed: T4.8, U4.1 (~Q8)
unnamed: T4.9, U4.2 (~Q9)
unnamed: T5.1, U5.15 (~Q1)
unnamed: T5.2, U5.8 (~Q2)
unnamed: T5.3, U5.9 (~Q3)
unnamed: T5.4, U5.13 (~Q4)
unnamed: T5.5, U5.14 (~Q5)
unnamed: T5.6, U5.11 (~Q6)
unnamed: T5.7, U5.10 (~Q7)
unnamed: T5.8, U5.1 (~Q8)
unnamed: T5.9, U5.2 (~Q9)
unnamed: T6.1, U6.15 (~Q1)
unnamed: T6.2, U6.8 (~Q2)
unnamed: T6.3, U6.9 (~Q3)
unnamed: T6.4, U6.13 (~Q4)
unnamed: T6.5, U6.14 (~Q5)
unnamed: T6.6, U6.11 (~Q6)
unnamed: T6.7, U6.10 (~Q7)
unnamed: T6.8, U6.1 (~Q8)
unnamed: T6.9, U6.2 (~Q9)
unnamed: SW1.2, U10.15 (RST)
RCLK: U7.12 (RCLK), U8.12 (RCLK), U9.12 (RCLK), U10.20 (IO34)
SCL: J3.3, U10.19 (IO9), U12.3 (C)
SCLK: U7.11 (SRCLK), U8.11 (SRCLK), U9.11 (SRCLK), U10.21 (IO36)
SDA: J3.2, U10.18 (IO8), U12.2 (D)
SIN: U7.14 (SER), U10.23 (IO35)
SOUT1: U7.9 (QH'), U8.14 (SER)
SOUT2: U8.9 (QH'), U9.14 (SER)
~OE: U7.13 (~OE), U8.13 (~OE), U9.13 (~OE), U10.17 (IO7)

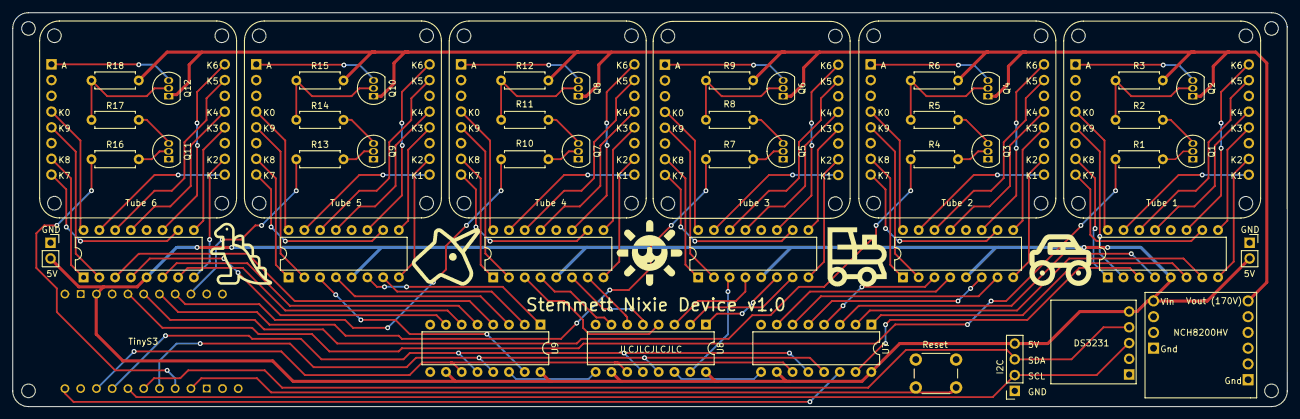
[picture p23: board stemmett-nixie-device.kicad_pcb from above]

Board: 2 copper layers, 205.5 x 63.5 mm, 56 parts (0 on the bottom side), 126 nets.

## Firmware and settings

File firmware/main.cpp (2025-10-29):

#include "Animation/animation.h"
#include "nixieDriver.h"
#include "rtc.h"
#include "tubeConfiguration.h"
#include "tubes.h"
#include "wifiServices.h"

#define LIGHT_SENSOR_PIN 8

// animation variables
Animation *animations[NUM_ANIMATIONS];
Animation *curAnimation = nullptr;
int curAnimationIndex = 0;
int curAnimationIndexSeq = 0;
hw_timer_t *refreshTimer;
volatile bool refreshTick = false;

WifiServices wifiServices;

// modified by rest API and displaySettingsTask
bool displayEnabled = true;
volatile int brightness = 150;
volatile float speedFactor = 1;

// timers for day/night transition
unsigned long dayNightTransitionLastUpdateMillis = 0;
unsigned long dayNightTranstionUpdateInteralMs = 0;

// light sensor variables
const unsigned long LightSensorReadIntervalMs = 1000;
const unsigned long LightSensorMinModeChangeIntervalMs = 10 * 1000;
const int LightSensorReadings = 20;
uint16_t lightSensorReadings[LightSensorReadings];
uint16_t lightSensorAverageReading = lightSensorThreshold;
unsigned long lightSensorLastReadMillis = 0;
unsigned long lightSensorLastModeChangeMillis = 0;

void IRAM_ATTR refreshTimerCallback()
{
  refreshTick = true;
}

bool ableToTransition()
{
  // check if any animations are enabled other than the name animation
  for (int i = 1; i < NUM_ANIMATIONS; i++)
  {
    if (!isNightMode && animationsEnabledDay[i])
      return true;
    else if (isNightMode && animationsEnabledNight[i])
      return true;
  }

  log_d("No animations enabled for current mode, not able to transition");
  return false;
}

bool isEnabled(int animationIndex)
{
  if (animationIndex < 0 || animationIndex >= NUM_ANIMATIONS)
  {
    log_e("Invalid animation index: %d", animationIndex);
    return false;
  }

  return isNightMode ? animationsEnabledNight[animationIndex] : animationsEnabledDay[animationIndex];
}

void instantiateAllAnimations()
{
  // initialize animations
  animations[AnimationType::BasicFade] = new BasicFadeAnimation();
  animations[AnimationType::Bubble] = new BubbleAnimation();
  animations[AnimationType::CylonScan] = new CylonScanAnimation();
  animations[AnimationType::Ghost] = new GhostAnimation();
  animations[AnimationType::Name] = new NameAnimation();
  animations[AnimationType::NameGlitch] = new NameGlitchAnimation();
  animations[AnimationType::Pulsar] = new PulsarAnimation();
  animations[AnimationType::Rain] = new RainAnimation();
  animations[AnimationType::RandomScan] = new RandomScanAnimation();
  animations[AnimationType::Scan] = new ScanAnimation();
  animations[AnimationType::SlotMachine] = new SlotMachineAnimation();
  animations[AnimationType::TubeTest] = new TubeTestAnimation();
}

void initializeNextAnimation()
{
  log_d("Initializing next animation");

  int newAnimationIndex;
  if (curAnimationIndex == AnimationType::Name && ableToTransition())
  {
    do
    {
      // both behaviors exclude name animation at index 0
      if (transitionBehavior == TransitionBehavior::Sequential)
      {
        curAnimationIndexSeq = (curAnimationIndexSeq + 1) % NUM_ANIMATIONS;
        newAnimationIndex = curAnimationIndexSeq;
      }
      else if (transitionBehavior == TransitionBehavior::Random)
      {
        newAnimationIndex = random(1, NUM_ANIMATIONS);
      }
      else
      {
        log_e("Invalid transition behavior: %d", transitionBehavior);
        transitionBehavior = TransitionBehavior::Sequential;
        return;
      }

    } while (!isEnabled(newAnimationIndex) || newAnimationIndex == AnimationType::Name);

    log_d("Switching to animation %d", newAnimationIndex);
  }
  else
  {
    log_d("Switching to name animation");
    newAnimationIndex = AnimationType::Name;
  }

  curAnimationIndex = newAnimationIndex;
  curAnimation = animations[newAnimationIndex];
  curAnimation->initialize(Tubes, brightness, speedFactor);
  log_d("Initialized animation %d", newAnimationIndex);
}

void handleRefresh()
{
  if (transitionBehavior != TransitionBehavior::Sequential && transitionBehavior != TransitionBehavior::Random)
  {
    log_e("Transition behavior: %d is invalid", transitionBehavior);
    delay(10000);
    return;
  }

  if (refreshTick)
  {
    refreshTick = false;

    if (!displayEnabled) {
      nixieOff(Tubes);
      return;
    }

    if (curAnimation->isComplete())
    {
      initializeNextAnimation();
    }

    TickResult result = curAnimation->handleTick(Tubes);

    if (result.CathodeUpdate)
    {
      nixieDisplay(Tubes);
    }

    if (result.BrightnessUpdate)
    {
      nixieBrightness(Tubes);
    }
  }
}

void displaySettingsTask(void *pvParameters)
{
  while (1)
  {
// optional light sensor
#ifndef USE_DS3231_RTC
    if (millis() - lightSensorLastReadMillis > LightSensorReadIntervalMs)
    {
      // read and shift in new reading
      uint16_t curReading = analogRead(LIGHT_SENSOR_PIN);
      for (int i = LightSensorReadings - 1; i > 0; i--)
      {
        lightSensorReadings[i] = lightSensorReadings[i - 1];
      }
      lightSensorReadings[0] = curReading;

      // calculate average reading
      uint16_t sum = 0;
      for (int i = 0; i < LightSensorReadings; i++)
      {
        sum += lightSensorReadings[i];
      }
      lightSensorAverageReading = sum / LightSensorReadings;

      // check if enough time has passed since last mode change before changing again
      if (millis() - lightSensorLastModeChangeMillis > LightSensorMinModeChangeIntervalMs)
      {

        if (lightSensorAverageReading < lightSensorThreshold && !isNightMode)
        {
          log_i("Light sensor reading less than threshold: %d < %d, setting to night mode", lightSensorAverageReading, lightSensorThreshold);
          isNightMode = true;
          brightness = nightBrightness;
          speedFactor = animationNightSpeedFactor;
          if (curAnimation != nullptr) {
            curAnimation->setBrightness(brightness);
            curAnimation->setSpeed(speedFactor);
          }
          lightSensorLastModeChangeMillis = millis();
        }
        // don't go day mode ever at night
        else if (!isNight && lightSensorAverageReading >= lightSensorThreshold && isNightMode)
        {
          log_i("Light sensor reading greater than threshold: %d > %d, setting to day mode", lightSensorAverageReading, lightSensorThreshold);
          isNightMode = false;
          brightness = dayBrightness;
          speedFactor = animationDaySpeedFactor;
          if (curAnimation != nullptr) {
            curAnimation->setBrightness(brightness);
            curAnimation->setSpeed(speedFactor);
          }
          lightSensorLastModeChangeMillis = millis();
        }
      }

      lightSensorLastReadMillis = millis();
    }
#endif

    if (isNtpSynced && millis() - dayNightTransitionLastUpdateMillis > dayNightTranstionUpdateInteralMs)
    {
      log_d("Updating brightness and speed");

      int delaySecs, hour, minute, second;

      rtcGetTime(hour, minute, second);

      int curMins = hour * 60 + minute;
      int minsToDay = (dayTransitionTime.tm_hour * 60 + dayTransitionTime.tm_min - curMins + 1440) % 1440;
      int minsToNight = (nightTransitionTime.tm_hour * 60 + nightTransitionTime.tm_min - curMins + 1440) % 1440;

      // if minsToDay or minsToNight are 0, it means the transition time is the current time so we want the other value
      if (minsToDay == 0)
      {
        minsToDay = 1440;
      }
      if (minsToNight == 0)
      {
        minsToNight = 1440;
      }


      isNight = minsToDay < minsToNight;
      log_i("Current time: %02d:%02d, %s, mins to day: %d, mins to night: %d", hour, minute, isNightMode ? "night" : "day", minsToDay, minsToNight);

      // when we transition to day we check light sensor before going to day mode
      isNightMode = isNight ? true : lightSensorAverageReading > lightSensorThreshold; 
      log_i("Setting to %s mode", isNightMode ? "night" : "day");

      brightness = isNightMode ? nightBrightness : dayBrightness;
      speedFactor = isNightMode ? animationNightSpeedFactor : animationDaySpeedFactor;
      if (curAnimation != nullptr) {
        curAnimation->setBrightness(brightness);
        curAnimation->setSpeed(speedFactor);
      }
      delaySecs = 60 * (isNightMode ? minsToDay : minsToNight);

      String timeOfDay = isNightMode ? "night" : "day";
      log_i("Setting brightness to %d and speed factor to %.2f (%s), next check in %dm", brightness, speedFactor, timeOfDay, delaySecs / 60);

      dayNightTranstionUpdateInteralMs = delaySecs * 1000;
      dayNightTransitionLastUpdateMillis = millis();
    }

    delay(10);
  }

  log_e("DisplaySettingsTask ended unexpectedly");
}

void setup()
{
  Serial.begin(115200);
  delay(5000);
  log_i("Starting setup");

  // fully async including wifi setup
  wifiServices.setup(DEVICE_NAME);
  wifiServices.createTask();

  loadSettings();
  nixieSetup();
  rtcSetup();

  // task to update brightness and speed
  xTaskCreate(displaySettingsTask, "DisplaySettingsTask", 8192, NULL, 10, NULL);

  refreshTimer = timerBegin(1000000); // 1Mhz (1,000,000 Hz)
  timerAttachInterrupt(refreshTimer, &refreshTimerCallback);
  timerAlarm(refreshTimer, REFRESH_RATE_US, true, 0);

  // start first animation
  instantiateAllAnimations();
  curAnimationIndex = AnimationType::TubeTest;
  curAnimation = animations[AnimationType::TubeTest];
  curAnimation->initialize(Tubes, brightness, speedFactor);

  log_i("Setup complete");
}

void loop()
{
  handleRefresh();
}

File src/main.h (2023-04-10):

//
// T6 | T5 | T4 | T3 | T2 | T1
//
#define EN_PIN 7      // OE pin
#define LATCH_PIN 34  // RCLK pin
#define PWM_PIN_1 1   // PWM pin for tube 1 anode
#define PWM_PIN_2 2   // PWM pin for tube  anode
#define PWM_PIN_3 3   // PWM pin for tube  anode
#define PWM_PIN_4 4   // PWM pin for tube  anode
#define PWM_PIN_5 5   // PWM pin for tube  anode
#define PWM_PIN_6 6   // PWM pin for tube  anode

#define NUM_TUBES 6

#define PWM_MAX 255
#define PWM_MIN 0
#define PWM_FREQUENCY 200 
#define PWM_RESOLUTION 8
#define REFRESH_RATE_US 1000  // 1ms

//|IN-4 |IN-7 |IN-7A|IN-7B|
//|  0  |  -  |     |     |
//|  1  |  П  |  M  |     |
//|  2  |  +  |  +  |  S  |
//|  3  |  m  |  m  |  ㎐ |
//|  4  |  A  |  %  |     |
//|  5  |  V  |     |     |
//|  6  |  M  |  µ  |  V  |
//|  7  |  Ω  |  -  |     |
//|  8  |  ~  |  к  |  Ω  |
//|  9  |  к  |  П  |     |

typedef enum {
  IN4 = 0,
  IN7 = 1,
  IN7A = 2,
  IN7B = 3,
} TubeType;

typedef enum {
  IN4_0 = 0,
  IN4_1 = 1,
  IN4_2 = 2,
  IN4_3 = 3,
  IN4_4 = 4,
  IN4_5 = 5,
  IN4_6 = 6,
  IN4_7 = 7,
  IN4_8 = 8,
  IN4_9 = 9,
} IN4_Cathodes;

typedef enum {
  IN7_Minus = 0,
  IN7_Pi = 1,
  IN7_Plus = 2,
  IN7_m = 3,
  IN7_A = 4,
  IN7_V = 5,
  IN7_M = 6,
  IN7_Omega = 7,
  IN7_Tilda = 8,
  IN7_Kappa = 9,
} IN7_Cathodes;

typedef enum {
  IN7A_M = 1,
  IN7A_Plus = 2,
  IN7A_m = 3,
  IN7A_Percent = 4,
  IN7A_Mu = 6,
  IN7A_Minus = 7,
  IN7A_Kappa = 8,
  IN7A_Pi = 9,
} IN7A_Cathodes;

typedef enum {
  IN7B_S = 2,
  IN7B_Hz = 3,
  IN7B_V = 6,
  IN7B_Omega = 8,
} IN7B_Cathodes;

const uint8_t TubeCathodeCount[4] = {10, 10, 8, 4};
const uint8_t TubeCathodes[4][10] = {
  {IN4_0, IN4_1, IN4_2, IN4_3, IN4_4, IN4_5, IN4_6, IN4_7, IN4_8, IN4_9},
  {IN7_Minus, IN7_Pi, IN7_Plus, IN7_m, IN7_A, IN7_V, IN7_M, IN7_Omega, IN7_Tilda, IN7_Kappa},
  {IN7A_M, IN7A_Plus, IN7A_m, IN7A_Percent, IN7A_Mu, IN7A_Minus, IN7A_Kappa, IN7A_Pi},
  {IN7B_S, IN7B_Hz, IN7B_V, IN7B_Omega}
};

typedef struct {
  const TubeType Type;
  const uint8_t PrimaryCathode;
  const uint8_t AnodePin;
  volatile int Delay;
  uint8_t ActiveCathode;
  uint8_t PwmPhase;
  // int PwmStart;
  // int PwmEnd;
} Tube;

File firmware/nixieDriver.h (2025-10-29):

#include <Arduino.h>
#include <SPI.h>
#include "tubeConfiguration.h"
#include "tubes.h"

void nixieSetup() {
  log_d("Setting up nixie tubes");
  pinMode(EN_PIN, OUTPUT);
  digitalWrite(EN_PIN, LOW);
  pinMode(LATCH_PIN, OUTPUT);
  digitalWrite(LATCH_PIN, LOW);
  for (int i = 0; i < NUM_TUBES; i++) {
    pinMode(Tubes[i].AnodePin, OUTPUT);
    digitalWrite(Tubes[i].AnodePin, LOW);
  }

  SPI.begin();

  // zero out cathode buffer
  SPI.transfer(0x00);
  SPI.transfer(0x00);
  SPI.transfer(0x00);

  // setup PWM for each tube
  for (int i = 0; i < NUM_TUBES; i++) {
    ledcAttach(Tubes[i].AnodePin, PWM_FREQUENCY, PWM_RESOLUTION);

    // calculate PWM phase offset for each tube to smooth out power consumption
    int phaseDeg = (360 / NUM_TUBES) * i;
    Tubes[i].PwmPhase = (phaseDeg / 360.0) * (pow(2, PWM_RESOLUTION));

    // Set initial brightness
    ledcWrite(Tubes[i].AnodePin, 128);
  }

  log_d("Nixie tubes setup complete");
}

void nixieDisplay(Tube tubes[NUM_TUBES]) {
  // each tube (at most 10 digits/cathodes) is encoded by 4 bits, so need 3
  // total bytes to shift out all tube data to three 8-bit registers
  digitalWrite(LATCH_PIN, LOW);

  for (int i = NUM_TUBES - 1; i >= 1; i -= 2) {
    uint8_t nibble1 = tubes[i].ActiveCathode;
    uint8_t nibble2 = tubes[i - 1].ActiveCathode;
    SPI.transfer((0xF0 & (nibble1 << 4)) | (0x0F & nibble2));
  }

  digitalWrite(LATCH_PIN, HIGH);
}

void nixieBrightness(Tube tubes[NUM_TUBES]) {
  for (int i = 0; i < NUM_TUBES; i++) {
    ledcWrite(tubes[i].AnodePin, tubes[i].Brightness);
  }
}

void nixieOff(Tube tubes[NUM_TUBES]) {
  for (int i = 0; i < NUM_TUBES; i++) {
    ledcWrite(tubes[i].AnodePin, 0);
  }
}

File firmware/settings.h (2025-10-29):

#pragma once

#ifdef USE_PREFERENCES
#include <Preferences.h>
Preferences preferences;
#endif

#include "Animation/animation.h"

bool preferencesInitialized = false;

// animation settings
bool animationsEnabledDay[NUM_ANIMATIONS];
bool animationsEnabledNight[NUM_ANIMATIONS];
float animationDaySpeedFactor;
float animationNightSpeedFactor;
TransitionBehavior transitionBehavior = TransitionBehavior::Sequential;

// brightness settings
struct tm dayTransitionTime;
int dayBrightness;
struct tm nightTransitionTime;
int nightBrightness;
uint16_t lightSensorThreshold = 512;

// based only off current time
bool isNight;

// based off light sensor and  current time (always night mode at night, sometimes night mode at day when light sensor is low)
bool isNightMode;

void initSettings()
{
 
#ifdef USE_PREFERENCES
  if (!preferencesInitialized)
  {
    preferences.begin("stemmett", false);
    preferencesInitialized = true;
    log_i("Initialized preferences");
  }
#endif
}

void loadSettings()
{
  log_d("Loading settings");

#ifdef USE_PREFERENCES
  initSettings();

  // use default settings until settings are modified by user
  bool isCustom = preferences.getBool("custom", false);
  if (isCustom)
  {
    log_i("Using custom settings");

    for (int i = 1; i < NUM_ANIMATIONS; i++)
    {
      String key = "a" + String(i);
      animationsEnabledDay[i] = preferences.getBool(key.c_str(), true);
    }
    for (int i = 1; i < NUM_ANIMATIONS; i++)
    {
      String key = "A" + String(i);
      animationsEnabledNight[i] = preferences.getBool(key.c_str(), true);
    }
    animationDaySpeedFactor = preferences.getFloat("ds", 1.0F);
    animationNightSpeedFactor = preferences.getFloat("ns", 1.0F);
    transitionBehavior = (TransitionBehavior)preferences.getUChar("tb", 0);
    preferences.getBytes("dtt", &dayTransitionTime,
                         sizeof(dayTransitionTime));
    dayBrightness = preferences.getUChar("db", 255);
    preferences.getBytes("ntt", &nightTransitionTime,
                         sizeof(nightTransitionTime));
    nightBrightness = preferences.getUChar("nb", 255);
  }
  else
  {
#endif
    // default settings
    log_i("Using default settings");

    for (int i = 1; i < NUM_ANIMATIONS; i++)
    {
      animationsEnabledDay[i] = true;
      animationsEnabledNight[i] = false;
    }

    animationsEnabledNight[AnimationType::Name] = true;
    animationsEnabledNight[AnimationType::BasicFade] = true;
    animationsEnabledNight[AnimationType::Bubble] = true;
    animationsEnabledNight[AnimationType::CylonScan] = true;
    animationsEnabledNight[AnimationType::Ghost] = true;
    animationsEnabledNight[AnimationType::Scan] = true;
    animationsEnabledNight[AnimationType::SlotMachine] = true;

    animationsEnabledDay[AnimationType::TubeTest] = false;
    animationsEnabledNight[AnimationType::TubeTest] = false;

    animationDaySpeedFactor = 1.0F;
    animationNightSpeedFactor = 0.15F;
    transitionBehavior = TransitionBehavior::Sequential;
    dayTransitionTime = {8, 0, 0, 0, 0, 0, 0, 0, 0};
    dayBrightness = 255;
    nightTransitionTime = {19, 0, 0, 0, 0, 0, 0, 0, 0};
    nightBrightness = 32;
#ifdef USE_PREFERENCES
  }
#endif
}

void saveSettings()
{
#ifdef USE_PREFERENCES
  log_d("Saving settings");

  initSettings();

  // this disables the default settings
  preferences.putBool("custom", true);

  for (int i = 1; i < NUM_ANIMATIONS; i++)
  {
    String key = "a" + String(i);
    preferences.putBool(key.c_str(), animationsEnabledDay[i]);
  }
  for (int i = 1; i < NUM_ANIMATIONS; i++)
  {
    String key = "A" + String(i);
    preferences.putBool(key.c_str(), animationsEnabledNight[i]);
  }
  preferences.putFloat("ds", animationDaySpeedFactor);
  preferences.putFloat("ns", animationNightSpeedFactor);
  preferences.putUChar("tb", transitionBehavior);
  preferences.putBytes("dtt", &dayTransitionTime,
                       sizeof(dayTransitionTime));
  preferences.putUChar("db", dayBrightness);
  preferences.putBytes("ntt", &nightTransitionTime,
                       sizeof(nightTransitionTime));
  preferences.putUChar("nb", nightBrightness);

  log_i("Saved settings");
#else
  log_w("Preferences not enabled, settings not saved");
#endif
}

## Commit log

2023-04-10 basic PWM animation
2023-05-06 slotmachineanimation updates
2023-05-12 slotHelper refactor
2023-05-13 slot helper fixes
2023-05-14 cylon and slot helper refactoring
2023-05-22 slot helper refactor, other updates
2023-06-27 renaming animations and fixes
    [main.cpp]
2023-06-27 slot helper update+
2024-01-26 adding kicad files
    [IN4-180D-socket.kicad_pcb, IN4-180D-socket.kicad_sch, IN7-0D-socket.kicad_pcb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]
2024-07-05 day/night animation control and bug fixes for brightness transitioning
    [main.cpp, settings.h]
2024-12-11 various updates/refactor, tasks, light sensor
2024-12-12 control for light threshold, fixes
    [main.cpp, settings.h]
2025-10-02 pwm fixes
2025-10-16 3DP design files for two different cases/enclosures
    [Stemmett Case Backplate.3mf, Stemmett Case Backplate.f3d, Stemmett Shroud.3mf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]
2025-10-29 tube test boot anim
2025-10-30 custom tube config
2025-11-06 initial start for Bowen Nixie Device, rough schematic
    [bowen-nixie-device.kicad_pcb, bowen-nixie-device.kicad_sch, stemmett-nixie-device.kicad_pcb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]
2025-11-25 bowen schematic progress
    [bowen-nixie-device.kicad_sch]
2026-01-15 schematic passing ERC
    [bowen-nixie-device.kicad_sch]
2026-01-15 rough initial layout
    [bowen-nixie-device.kicad_pcb, bowen-nixie-device.kicad_sch]
2026-03-18 bowen progress
    [bowen-nixie-device.kicad_pcb, bowen-nixie-device.kicad_sch]
2026-04-09 bowen layout progress
    [bowen-nixie-device.kicad_pcb]
2026-04-09 pcb tracing progress
    [bowen-nixie-device.kicad_pcb]
2026-04-09 more trace adjs
    [bowen-nixie-device.kicad_pcb]
2026-04-13 trace progress, gnd plane and most traces
    [bowen-nixie-device.kicad_pcb, bowen-nixie-device.kicad_sch]
2026-04-13 layout final
    [bowen-nixie-device.kicad_pcb, bowen-nixie-device.kicad_sch]
2026-04-14 bowen passing drc layout
    [bowen-nixie-device.kicad_pcb]
2026-04-15 IN-4 0D socket
    [IN4-0D-socket.kicad_pcb, IN4-0D-socket.kicad_sch]
2026-04-15 IN-7 180D socket
    [IN7-180D-socket.kicad_pcb, IN7-180D-socket.kicad_sch]
2026-04-15 IN-7 90D socket
    [IN7-90D-socket.kicad_pcb, IN7-90D-socket.kicad_sch]
2026-04-17 bowen updates
    [bowen-nixie-device.kicad_pcb, bowen-nixie-device.kicad_sch]
2026-07-21 add bowen readme
    [bowen-nixie-device.kicad_pcb]
2026-07-29 bowen minor updates
    [IN7-270D-socket.kicad_pcb, bowen-nixie-device.kicad_pcb, bowen-nixie-device.kicad_sch]
2026-07-30 final hardware updates maybe
    [IN4-0D-socket.kicad_pcb, IN4-180D-socket.kicad_pcb, IN7-0D-socket.kicad_pcb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]
2026-10-12 pin mapping fixes
